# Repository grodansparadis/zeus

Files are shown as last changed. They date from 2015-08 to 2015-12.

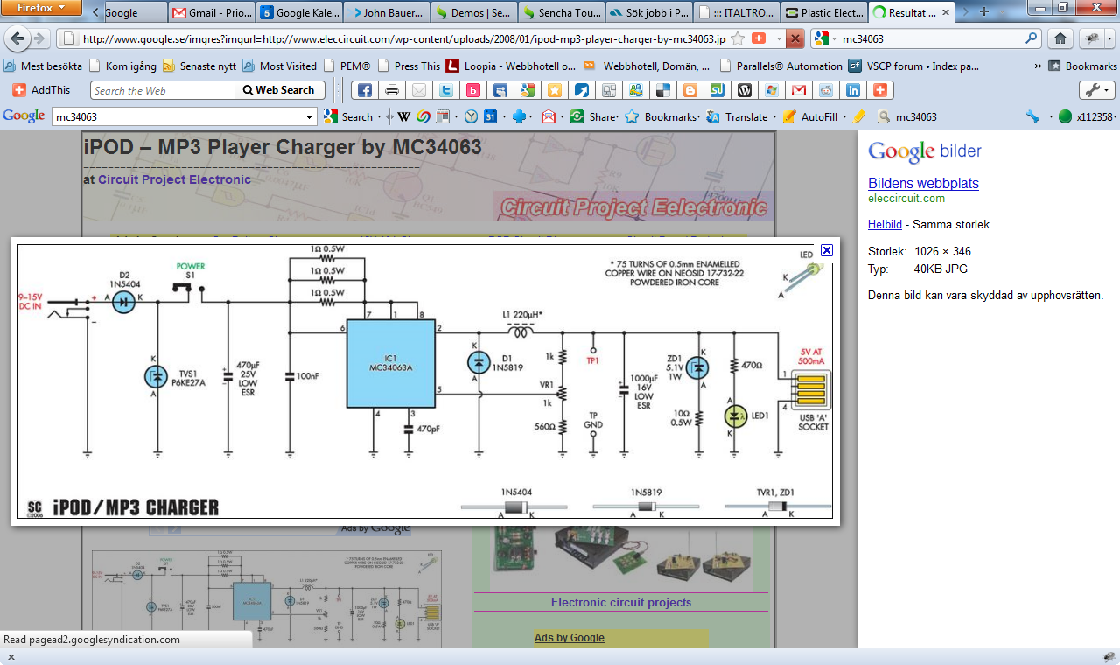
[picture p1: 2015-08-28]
docs/2011-05-05 16-10-04.png

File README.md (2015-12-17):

# zeus
Ethernet carrier board for VSCP
<hr>

This project is part of the <a href="http://www.vscp.org">VSCP (Very Simple Control Protocol) project</a>. 

<hr>

This project is licensed under the 
<a href="http://creativecommons.org/licenses/by-nc-sa/3.0/">Creative Commons open source license Attribution-NonCommercial-ShareAlike 3.0 Unported</a>. 
Other license options are available by conacting <a href="malto:info@grodansparadis.com">Paradis of the Frog AB</a>

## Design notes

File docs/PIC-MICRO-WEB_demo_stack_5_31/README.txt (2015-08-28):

0. INTRODUCTION

It is highly recommended to read the excellent stack documentation from Microchip before proceeding. The demo is based on the original Microchip Application Libraries. The TCPIP version is 5.31 - part of Microchip Application Libraries v2010-10-19.

--------------------------------------------------------------------------------

1. RUNNING THE DEMO

You might use the prebuilt files in directory "Prebuilt". If you wish to build the demo yourself please continue reading.

Open "./TCPIP Demo App/TCPIP Demo App-C18.mcw" workspace. 

*Note: In order to compile successfully you need to have MC18 installed. Please also ensure that project directories are set properly to match path of the compiler (i.e. right-click the project->Build Options...->Directories tab).
	
Now you can compile the project and download it to the board. Of course, you can also use the project as a starting project for your custom application.

2. UPDATING THE WEB PAGE

The source web page files for PIC-MICRO-WEB are located in 
	./TCPIP Demo App/WebPagesOlimex"
	
You should run the "./Microchip/TCPIP Stack/Utilities/MPFS2.exe" to regenerate the image file (default is "MPFSImg2.bin") that shoulb be uploaded to the flash memory of the board.

Then, assuming PIC-WEB has IP address 192.168.0.30, open the following URL in your web browser: "http://192.168.0.30/mpfsupload". Browse to "MPFSImg2.bin" and upload it. After that the new web page should be available.

*Note: You might also use the ready MPFSImage2.bin located in directory "Prebuilt"

3. LOCATING PIC-WEB

Run the "./Microchip/TCPIP Stack/Utilities/Microchip Ethernet Discoverer.exe" utility in order to find what IP address has PIC-WEB fetched from DHCP. Another option is to connect a serial port to the board RS232 connector, configure your terminal application for 19200 8N1, and see the board status messages during power up.

*Note: Default setting of the board is to use DHCP to retrieve network configuration (IP address, etc.).. This can be modified by editing the "TCPIPConfig.h".

Last edit: 11 Nov 2013

Special thanks to Paolo for providing this demo!

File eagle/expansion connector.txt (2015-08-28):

Pinput for expansion connector
==============================

1	GND
2	GND
3	RC7/RX1/DT1		Motherboard RX. Output on daughterboard.
4	RC6/TX1/CK1		Motherboard TX. Output on daughterboard.
5	SCK1 (SCL1)		SPI or I2C clock. (Add 4.7K pull-up for I2C on daughterboard)
6	SDI1 (SDA1)		SPI data in or I2C data. (Add 4.7K pull-up for I2C on daughterboard)
7	SDO1 			SPI data out.
8	RF2/AN7/C1OUT	Analog or digital pin.
9	RF3/AN8			Analog or digital pin.
10	RF4/AN9			Analog or digital pin.
11	RF5/AN10/CVREF	Analog or digital pin.
12	RF6/AN11		Analog or digital pin.
13	RG4/CCP5/P1D	Digital or capture compare input.
14	RESET			System reset. Pulled up on motherboard.
15	RB3/INT3		Digital or INT3
16	RB2/INT2		Digital or INT2
17	RB1/INT1		Digital or INT1
18	RB0/INT0/FLT0	Digital or INT0
19	RE2/P2B			Digital.
20	RE3/P3C			Digital.
21	RE0/P2D			Digital.
22	RE1/P2C			Digital.
23	+3.3V
24	+3.3V

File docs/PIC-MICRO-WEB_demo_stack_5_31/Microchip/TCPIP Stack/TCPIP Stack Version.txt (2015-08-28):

********
Microchip TCP/IP Stack Version Log:
********

Note: Please file bug-reports/bug-fixes at http://support.microchip.com/ or post 
      to the Microchip TCP/IP -> Ethernet Forum at http://forum.microchip.com/
      Look for stack updates at http://www.microchip.com/tcpip/

********
v5.31 		19 October 2010
********
Changes:
1.  Reorganized demo projects.  The TCPIP ENCX24J600 Demo App, TCPIP PIC32 ETH 
    Demo App, and TCPIP WiFi Demo App projects in stack versions 5.25 and prior 
    have all been merged into the TCPIP Demo App folder.  All four of these 
    projects were almost identical to each other, with the primary difference 
    being the network interface controller the projects were preconfigured to 
    support.  In this 5.31 TCP/IP Stack release, each hardware combination now 
    has its own MPLAB IDE project in the TCPIP Demo App folder.
2.  Reorganized HardwareProfile.h and TCPIPConfig.h structure for the TCPIP Demo 
    App, TCPIP Google PowerMeter Demo App, and TCPIP WebVend App projects.  Now, 
    instead of having one massive HardwareProfile.h file that supports a 
    multitude of hardware platforms simultaneously, simple individual 
    hardware profiles have been created for specific hardware combinations and 
    placed in the "Alternative Configurations" sub-folder.  The correct hardware 
    profile or TCPIP config file is selected by #including "HardwareProfile.h" 
    or "TCPIPConfig.h" as in previous stack versions.  However, the active 
    hardware profile or config file from the Alternative Configurations folder 
    is selected by a preprocessor macro defined in the MPLAB project settings 
    (passed on the command line to the compiler).
3.  Added HTTP_SAVE_CONTEXT_IN_PIC_RAM option to TCPIPConfig.h (HTTP2 server 
    module).  This option, when enabled, will increase HTTP2 server performance 
    when servicing multiple simultaneous connections at the expense of using 
    more PIC RAM.
4.  Added automatic TPIN+/- polarity swapping logic to ETH97J60.c driver for 
    PIC18F97J60 family devices.  Some 3rd party Ethernet switches, routers, and 
    end devices have their TX+/- pins wired backwards such that the remote TX+ 
    signal connects to the PIC TPIN- pin and the remote TX- signal connects to 
    the PIC TPIN+ pin.  Because 10BaseT Ethernet signaling is polarized and the 
    PIC18F97J60 family does not implement an auto-polarity feature, this 
    normally prevents all RX communications with these non-IEEE 802.3 compliant 
    link partners.  To work around this incompatibility, it is possible to 
    implement circuitry to swap the RX+ and RX- signals before reaching the 
    TPIN+ and TPIN- pins.  The PICDEM.net 2 Rev 6 reference design includes this 
    necessary circuitry (U6, U7, R54, and RX_SWAP GPIO output pin from PIC).  
    This stack version automatically controls the RX_SWAP signal based on the 
    ETH_RX_POLARITY_SWAP_TRIS and ETH_RX_POLARITY_SWAP_IO definitions in 
    HardwareProfile.h.  If these macros are undefined, then the automatic 
    polarity swapping feature is disabled in the ETH97J60.c driver.
5.  Added portable LFSRRand() and LFSRSeedRand() public functions to Helpers.c 
    and removed all references to C rand() and srand() functions.  The C rand() 
    function returns a 15 bit integer on 8 and 16 bit PICs, but a 31 bit integer 
    on PIC32s.  The LFSRRand() function returns a 16-bit integer, regardless of 
    which PIC you are using.
6.  Added support for various SST/Microchip brand SST25xxxxx SPI Flash chips to 
    SPIFlash.c driver.  Previously only devices supporting the Auto Address 
    Increment (AAI) Word Program opcode (0xAD) would work.  Now, devices such as 
    the SST2525VF010A should work, which require the AAI Byte program opcode 
    (0xAF) instead.
7.  Removed support for Spansion brand SPI Flash chips in the SPIFlash.c driver.  
    If your application is already using one of these devices, continue to use 
    the SPIFlash.c/.h files from TCP/IP Stack 5.25.  These older files are API 
    compatible with the current version, so can be dropped in by simply 
    overwriting the SPIFlash.c and SPIFlash.h files.
8.  Removed a -4 offset from the advirtised TCP Maximum Segment Size option 
    (MSS) and TCP_MAX_SEG_SIZE_RX configuration value in TCP.c.  The default 
    TCP MSS advertised is now 536 instead of 532.    
9.  For Wi-Fi projects in the TCPIP Demo App folder, changed 
    MY_DEFAULT_LIST_RETRY_COUNT to WF_RETRY_FOREVER instead of 3.  This
    changes default connection behavior to keep trying to connect instead of
    just trying 3 times which makes more sense for demonstration.
10. Changed WF_Connect() beacon timeout to 40.
11. IFConfig command in TCPIP WiFi Console Demo App modified to return 
    application-perspective MAC address from the AppConfig structure, and not 
    the Wi-Fi serialized MAC address (they may not match if user desired custom 
    MAC).
12. Updated the TCP/IP Configuration Wizard.  The user can now configure 
    wireless settings and stack settings seperately.  Because of the changes to 
    the TCPIPConfig.h file, the user must now select the specific copy of 
    TCPIPConfig.h (or any of its variants) instead of selecting a project 
    directory. Added the ability to select WF_RETRY_FOREVER in the Wi-Fi 
    configuration settings.  Added a selection parameter for BSD socket count. 
    Added validation to check for the proper number of Berkeley sockets and TCP 
    performance test sockets in the socket configuration screen (Advanced 
    Settings) if either of these features are enabled.  Added the ability to 
    create sockets of the same type with different TX/RX buffer sizes in the 
    socket configuration screen.
13. Updated the TCPIP WebVend Demo App to support Wi-Fi in several 
    configurations.
14. Modified the Google PowerMeter demo to automatically determine the 
    date/time from the HTTP module if the date/time cannot be obtained from the 
    SNTP module.
15. Added a new Google Map project example to the Combo Demos folder.  This 
    example runs on a PIC24FJ256DA210 Development Board + Fast 100Mbps Ethernet 
    PICtail Plus (or Ethernet PICtail Plus) + Truly 3.2" 240x320 display, 
    TFT_G240320LTSW_118W_E (or Powertip 4.3" 480x272 display, 
    PH480272T_005_I11Q).  It also can run on the PIC32 Multimedia Expansion 
    Board + PIC32 Ethernet Starter Kit.  This demo connects to the Internet, 
    sends an HTTP query for a specific map tile to the Google Static Maps API, 
    and then displays the compressed tile to the graphics display.  For more 
    information, see the "Getting Started - Running the Graphics Google Map 
    Demo.htm" file in the Combo Demos\Google Map folder.
16. Added preliminary SNMPv3 module.  This module, enabled with the 
    STACK_USE_SNMPV3_SERVER option in TCPIPConfig.h, implements the Simple 
    Network Management Protocol, version 3.  Among other things, SNMPv3 adds 
    secure authentication and cryptographic privacy as compared to SNMPv2C.  
    This implementation currently only supports AES encryption (no DES support).  
    It also has only been tested with the PIC32 Ethernet Starter Kit (TCPIP 
    Demo App - C32 - PIC32_ENET_SK_DM320004_INTERNAL_ETHERNET.mcp MPLAB IDE 
    project).  SNMPv3 on PIC18, PIC24, and dsPIC platforms are not supported at 
    this time.  Because AES encryption has specialized United States export 
    requirements, this TCP/IP Stack release does not include the required AES 
    library to enable SNMPv3.  To obtain the needed AES library, you must 
    purchase SW300052 v2.6 or later.  Older v2.5 and previous versions include 
    AES related files on them, but do not include the new AES files required by 
    SNMPv3.  For more information on using SNMP, refer to the TCP/IP Stack Help 
    (Demo Information -> Available Demos -> TCPIP Demo App -> Demo Modules -> 
    Network Management (SNMP) Server).
17. Altered the SaveAppConfig() function in MainDemo.c to store a more robust 
    signature to EEPROM/SPI Flash when saving the AppConfig structure.  In v5.25 
    and prior stack versions, when EEPROM or SPI Flash memory was available, the 
    stack would automatically write a one byte marker character to address 
    0x000000 in the EEPROM/Flash indicating if a valid AppConfig structure was 
    stored in the non-volatile memory.  This resulted in the EEPROM/Flash 
    contents being organized like the following:
        Address                 Data Contents
        ===================     ==============================================
        0x000000:               Marker Byte
        0x000001:               AppConfig structure
        MPFS_RESERVE_BLOCK:     Start of MPFS/MPFS2 image containing web pages
    In this stack version, EEPOM/Flash contents will now contain:
        Address                 Data Contents
        ===================     ==============================================
        0x000000:               Length of AppConfig structure (16-bit integer)
        0x000002:               IP checksum of the AppConfig default values, as 
                                defined in TCPIPConfig.h and WF_Config.h 
                                (16-bit integer).
        0x000004:               IP checksum of the subsequent EEPROM/Flash 
                                bytes of the AppConfig values.
        0x000006:               AppConfig structure
        MPFS_RESERVE_BLOCK:     Start of MPFS/MPFS2 image containing web pages
   The additional checkums allow automatic detection to occur if you change one 
   of the values in TCPIPConfig.h or WF_Config.h that affects AppConfig.  If 
   you change one of the values in code, then upon boot up, the application 
   will automatically detect this change and start using the values that you 
   selected in code.  If, at run time, you decide to change the AppConfig 
   values and commit the changes to EEPROM/Flash, then the stack will 
   subsequently use the run-time saved values on future reboots.  The checksum 
   at offset 0x000004 ensures that if any corrupted AppConfig contents are 
   found in EEPROM/Flash (ex: power is lost between writing the signature 
   structure and actual AppConfig structure, or code unintentionally overwrites 
   something in the AppConfig memory area), then the original defaults defined 
   in TCPIPConfig.h and WF_Config.h will be used instead of the corrupted 
   values.  This EEPROM/SPI Flash change affects all projects except TCPIP 
   Internet Radio App, TCPIP Internet Bootloader App, and all PIC32 Starter Kit 
   projects since these projects do not have or use external EEPROM or SPI 
   Flash memory.

Fixes:
1.  Fixed a UDP bug in which a transmitted packet would have been addressed 
    to the wrong destination node if the UDP socket received a broadcast packet 
    from a different remote node from the last received packet, but using the 
    same source port number as the last received packet.  The 
    FindMatchingSocket() function in UDP.c will now always change the local 
    socket parameters to send to the most recent remote node's unicast IP 
    address, regardless of if the last received packet was addressed to a 
    multicast or broadcast destination.  Thanks go to Billy Walton for reporting 
    this erroneous behavior.  If you wish to change the destination IP/MAC 
    addresses or port number for a UDP packet that you are ready to send, write 
    the new parameters to the UDPSocketInfo[SocketHandle] global structure 
    before calling UDPFlush().  This structure contains remoteNode and 
    remotePort parameters for the remote IP address/MAC address and remote UDP 
    port, respectively.  You can also read these values to obtain the remote 
    addressing parameters for the last received packet on the given UDP socket.  
    Note that "SocketHandle" refers to the UDP socket handle returned by the 
    UDPOpen() API, not the literal string "SocketHandle".
2.  Fixed ADC state save/restore bug in GenerateRandomDWORD() function in 
    Helpers.c.  PIC24, dsPIC, and PIC32 platforms require the ADC ON/ADON bit to 
    be cleared before modifying certain other ADC register contents.
3.  Fixed an ENC28J60 MAC/MII register write timing violation when using a 
    PIC24H or dsPIC at over 33MIPS.  There was inadequate Chip Select hold time 
    provided, violating the 210ns minimum specified in the ENC28J60 data sheet.  
    This violation may have resulted in certain devices losing the ability to 
    receive packets (due to the MARXEN bit, MACON1<0>, getting cleared 
    unintentionally).
4.  Fixed an ENCX24J600.c driver bug in which operating at 100Mbps with the 
    ENC424J600/624J600 Ethernet controller, it would be possible for the 
    MACGetHeader() function to issue a Reset() operation under rare 
    circumstances.  The PIC would reset whenever the PHY detected an illegal 
    symbol during 4B5B decoding but guessed the correct 4B symbol such that no 
    data corruption or CRC error occurred.  This condition results in a valid 
    packet being received but with the Received Ok Receive Status Vector bit 
    being clear (RSV<23> == 0).  This issue would become more probable when 
    using very long Ethernet cables (ex: 100 meters) and receiving a lot of 
    data.
5.  Fixed a TCP bug in which calling TCPDisconnect() to close a connection when 
    the remote node's RX window was 0 bytes would have caused the stack to enter 
    an infinite loop sending duplicate ACK packets.
6.  Fixed Wi-Fi bug that caused assert condition if too many management messages 
    were being received during data traffic.
7.  Fixed Wi-Fi bug that caused WF_EVENT_CONNECTION_RESTABLISHED event case to 
    send the wrong notification to the app.  
8.  Fixed Wi-Fi bug that caused assert failure with Scratch move failure.
9.  Fixed Wi-Fi bug in WF_CAGetChannelList() and WF_CAGetSecurity that caused 
    failure.
10. Fixed Wi-Fi EasyConfig bug that required development boards to be manually 
    reset even after new network was selected.
11. Fixed MRF24WB0 bug that caused assert if invalid WPA/WPA2 key was entered.
12. Fixed Wi-Fi power management bit behavior in PS-Poll frame that was causing 
    some AP’s to never send data or disconnect when in power save mode.
13. Fixed a TCP bug in which attempting to open a client TCP socket to a remote 
    server, specified by IP address (not DNS address), that was offline, but 
    who's MAC address was already cached by the ARP client, would result in 
    endless back-offs. For example, when attempting to contact the remote node 
    (that was not responding), the TCP module would have transmitted a SYN at 
    time T=0 seconds, T=1s, T=3s, T=7s, T=15s, T=31s, T=63s, T=127s, T=255s, 
    etc.  The exponential back-off between retransmissions would grow 
    indefinitely until the retransmission interval would have grown so large 
    that effectively no-retransmissions would be occurring.  Assuming the 
    application wasn't written with its own timeout to prevent endless waiting, 
    this would prevent the socket from automatically establishing the 
    connection to the remote server once the server came back online.  With this 
    TCP fix, the exponential back off now saturates after TCP_MAX_RETRIES (5) 
    back offs and continues to retransmit using the same interval.  By default, 
    this means SYN transmissions will occur at T=0 seconds, T=1s, T=3s, T=7s, 
    T=15s, T=31s, T=63s, T=95s, T=127s, etc.  After 5 back-offs the 
    retransmission interval stops growing and stays constant at 32 seconds.
14. Fixed an RSA computation bug that would cause the RSA module to never 
    complete if you attempted to compute y = x^e % n where e = 3 (or similar 
    number < 256 with only 0, 1, or 2 bits set).  Thanks go to Kevin Maidment 
    for pointing this error out and suggesting a solution.  Note, that this fix 
    to RSA.c is not distributed with the ordinary TCP/IP Stack due to United 
    States export restrictions.  To get this fix, you must repurchase SW300052.  
    This fix is included in SW300052 v2.6 or later.  If you don't have CD media 
    to identify the SW300052 version that you have, you can test the RSA.c file 
    that you have.  RSA.c in SW300052 v2.6 has a CRC32 checksum of 0x91F66711.  
    RSA.c in v2.5 and prior had a checksum of 0xB1E8B0CC.

Known Problems:
1.  Telnet server module does not implement a lot of Telnet functions.  As a 
    result, it will likely not display correctly or work at all with some Telnet 
    clients.  The server was tested with the Microsoft telnet.exe utility which 
    is provided with Microsoft Windows.
2.  If the DHCP client and DHCP server are used at the same time and you connect 
    two similar boards to each other (ex: two PICDEM.net 2 boards connected via 
    a crossover cable), a race condition can occur where both nodes will disable 
    their DHCP server and neither board will get a successful DHCP lease.  If 
    this unlikely scenario occurs, as a work around, simply reset one of the 
    boards to reenable it's DHCP server.
3.  LCDBlocking.c timing for the LCD_E_IO enable signal is too fast to meet 
    published data sheet limits for various LCD controllers when compiling for 
    a PIC32 running at > 43MHz.  Despite this potential timing violation, the 
    LCD does normally work correctly on the precompiled PIC32 demos for the 
    Explorer 16 at 80MHz.

********
v5.25 		07 May 2010
********
Changes:
1.  Added support for the Microchip MRF24WB0 802.11 WiFi controller (module 
    part number MRF24WB0MA).  This product is intended as a backwards 
    compatible, drop in replacement to the ZG2100.  The MRF24WB0MA should work 
    with previous TCP/IP Stack versions as if it were a ZG2100M, but when the 
    MRF24WB0MA is used with this (5.25) and future TCP/IP Stack versions, 
    feature improvements inside the MRF24WB0 allow the TCP/IP Stack code/RAM 
    size to be smaller and run faster.  
2.  Dropped support for the ZeroG ZG2100 802.11 WiFi controller.  Applications 
    that must stay with this device should continue to use TCP/IP Stack 
    version 5.20b or earlier.  All new projects or preexisting projects 
    undergoing updates should be developed with the MRF24WB0 instead.
3.  The WiFi connection management state machines now run on the MRF24WB0 
    instead of the PIC host, freeing up code and data space.  Connection profiles 
    can be created and the connection algorithm fine-tuned by the PIC 
    application. In the WiFi demos see the WF_Connect function in MainDemo.c for 
    an example of how to configure and then establish a WiFi connection.  The
    programming model has changed to an API model which is documented in 
    'TCPIP Stack Help.chm'.
4.  Changed "VERSION" macro definition in TCPIP.h to "TCPIP_STACK_VERSION".  
    "VERSION" is overly generic and will likely conflict with other identical 
    tokens one may use in their application code or source libraries.
5.  Added support for the PIC24FJ256GA110, PIC24FJ256GB110 and PIC24FJ256GB210
    PIMs for the Explorer 16.  Note that when using the PIC24FJ256GA110 
    general purpose PIM, the Ethernet PICtail Plus, Fast 100Mbps Ethernet 
    PICtail Plus, MRF24WB0MA Wi-Fi PICtail Plus, or other SPI PICtail daughter 
    board should be installed in the middle SPI2 slot of the Explorer 16, not 
    the ordinary topmost SPI1 slot used by other PIMs, including the 
    PIC24FJ256GB110 and PIC24FJ256GB210 ones.  The software is set up to use 
    SPI2 for the PIC24FJ256GA110 PIM to avoid incompatibilities with silicon 
    revision A3, which does not allow the SCK1 pin to be configured as a PPS 
    output.
6.  Added support for the PIC24FJ256DA210 Development Board.
7.  Added TFTPUploadRAMFileToHost(), TFTPUploadFragmentedRAMFileToHost() and 
    TFTPGetUploadStatus() APIs to the TFTPc.c file.  These APIs provide a very 
    simple means of uploading a whole file to a remote TFTP server without 
    requiring a great deal of application state machine logic.  These APIs 
    require the DNS client module to be enabled (STACK_USE_DNS must be defined, 
    in addition to STACK_USE_TFTP_CLIENT).
8.  Added a dummy DNS Server module.  This server always sends the local IP 
    address in response to all queries received.  When using the PIC DHCP 
    server, its purpose is to allow a user to type anything into a web browser 
    (ex: http://asdf/) and still receive the web page provided by the PIC, much 
    as a hotel or airport WiFi router will serve to you before you've paid or 
    agreed to the network's terms of service.  This DNS server module is 
    implemented in DNSs.c, requires one UDP socket, and is enabled via the 
    STACK_USE_DNS_SERVER option in TCPIPConfig.h.
9.  Changed SPIFlash.h file defaults to target an SST SPI Flash with 4096 byte 
    sectors instead of a Spansion Flash with 65536 byte sectors.  These new 
    defaults are, among other reasons, in support of the PIC24FJ256DA210 
    Development Board, which has an SST SST25VF016B on it.
10. Made TCP Keep-Alive packets consistently get sent TCP_KEEP_ALIVE_TIMEOUT 
    (default 10 seconds) after the last socket TX or RX activity.  In earlier 
    stack versions, if the local node transmitted some data and then let the 
    socket go idle, the first Keep-Alive packet sent would use the 
    TCP_START_TIMEOUT_VAL (default 1 second) timer value before getting sent.  
    While benign in terms of application behavior, these faster than normal 
    keep-alive transmissions were distracting when viewed in Wireshark or other 
    packet capture tools.
11. Disabled STACK_USE_DYNAMICDNS_CLIENT option in TCPIPConfig.h by default for 
    the TCPIP Demo App and TCPIP ENCX24J600 Demo App projects.  This option was 
    enabled by default in earlier stack releases.  This was done to save code 
    size and allow out-of-box compilation on devices with 128KB of Flash when 
    not using compiler optimizations.  The TCPIP PIC32 ETH Demo App project 
    continutes to have this option enabled by default.
12. Added SNMP v2 TRAP PDU format.  Macro SNMP_STACK_USE_V2_TRAP is used to 
    enable the SNMP v2 trap format.  New API function SNMPV2TrapDemo() is 
    included to support more than one variable binding to the SNMPv2 TRAP. This 
    API can be used for a single SNMPv2 TRAP variable varbind and is part of 
    CustomSNMPApp.c. A multiple variable binding demo can be enabled 
    MainDemo.c.  One should not enable both SNMPTrapDemo and SNMPV2TrapDemo 
    simultaneously.  Global flag "gSetTrapSendFlag" is used to indicate the 
    start and end of SNMPv2 trap varbinds.  If gSetTrapSendFlag is FALSE, then 
    very next variable varbind for the SNMPv2 TRAP, is the last or only one 
    variable varbind.  If gSetTrapSendFlag is TRUE, then there is another 
    variable varbind available to be part of the SNMPv2 TRAP PDU.
13. Added support for PIC32MX6XX/7XX external PHY's: SMSC 8700LAN and National 
    DP83640.
14. Added schematics and BOM for the PIC32 Ethernet Starter Kit.
15. Added the Google PowerMeter demo project. Consult the "Reference 
    Implementation for Google PowerMeter.chm" help file for more information.
16. Modified the SSL and TCP modules to create the TCPStartSSLClientEx function.
    This function will enable the SSL module to store supplementary data
    (currently only SSL Certificate Public Keys) in a structure.
17. Moved the HTTP_PORT, HTTPS_PORT, HTTP_MAX_DATA_LEN, and HTTP_MIN_CALLBACK_FREE
    macros from HTTP2.c to TCPIPConfig.h.

Fixes:
1.  The SPIFlashEraseSector() function in the SPIFlash.c file incorrectly erased 
    the sector specified by the current write pointer (set by calling 
    SPIFlashBeginWrite()) instead of the specified dwAddr parameter address.  
    This error had no impact on any TCP/IP Stack code as these parameters always 
    matched.  However, application code using the API would have been affected.  
    Thanks go to Marc Boon for reporting this issue on the Microchip Ethernet 
    forum.
2.  Fixed ENC424J600/624J600 driver for PSP modes 2, 4, 6, and 10.  The PIC's 
    PMP PMMODE<9:8> bits were not set correctly.
3.  Removed from lingering references to TickGetDiff() in FTP.c, TFTPc.c and 
    UARTConfig.c.
4.  Fixed DNS client module from returning the DNS server IP address if the DNS 
    query failed due to a server error (i.e. DNS did respond, but did not 
    return any records, such as when attempting to resolve a name that isn't in 
    the DNS).  DNSIsResolved() will now return 0.0.0.0 on any non-recoverable 
    DNS error or timeout.
5.  Fixed HTTP2 MPFS upload page being accessible from URLs that weren't an 
    exact match.  For example, in 5.20 and earlier, accessing 
    http://mchpboard/mpfsuploadASDF would still have opened the mpfsupload page.  
    Thanks go to Andrea Rivolta on the Microchip Ethernet Forum for identifying 
    this error.
6.  Improved UDP TX checksum code for the special case when the computed 
    checksum was 0x0000.  According to the UDP RFC, for this corner case, the 
    checksum should be converted to 0xFFFF before transmission to differentiate 
    from the checksum disabled case, improving error detection by a minuscule 
    amount.
7.  Fixed GetCLKOUT() function in ENCX24J600.c driver file.  Previously, 0x00 
    would always be returned, regardless of the value in the COCON bits of 
    ECON2.  The function documentation for SetCLKOUT() and GetCLKOUT() was also 
    corrected (had obsolete information ported over from ENC28J60 driver file).
8.  Fixed DHCP client rebinding bug in which the DHCP client would request the 
    wrong IP address if an unrelated DHCP OFFER or ACK message were received 
    after we transmitted a DHCP REQUEST but before we received our DHCP ACK. 
    Under rare conditions, this would have resulted in the TCP/IP stack 
    reverting to the static or AutoIP assigned address for a few seconds 
    between DHCP lease renewals.
9.  Fixed TFTP Internet Bootloader bug in which uncommon .hex files containing 
    a certain data pattern could not be uploaded correctly to the PIC18F97J60 
    family device.  For these problem .hex files, a block of 32 program words 
    (64 bytes) would remain unprogrammed (left as 0xFFFF) due to a parsing error 
    in the bootloader's DecodeHex() function.  The TFTP upload operation would 
    succeed without reporting a programming error.  The problem can be detected 
    by using an ICD3 or similar ICSP programmer and reading the program Flash 
    out of a device that is programmed with the bootloader and application .hex 
    files.  Compare the resulting memory dump to a device programmed only with 
    the application .hex file.  If you have devices deployed in the field with 
    the previous bootloader and happen to generate a  problem application .hex 
    file, you can potentially work around the bootloader bug by opening the 
    application .hex file with Notepad and appending dummy address records to 
    the beginning to move the data around in the file.  For example, at the very 
    top of the .hex file, add lines containing ":020000040000FA" until the 
    bootload process works correctly.  You may alternatively try adding spaces 
    at the end of any line, although this may make the .hex file incompatible 
    with some programming utilities.  Thanks go to Jonathan Seidmann for 
    identifying and reporting this bug.
10. Fixed SNMPv2 TRAP format issue where SNMP browser was displaying all the 
    SNMPv2 traps as SNMP version 1.  SNMP v2 TRAP pdu format is rectified.  
    Macro SNMP_STACK_USE_V2_TRAP is used to form and send a SNMPv2 TRAP PDU.  
    SNMPTrapDemo API is used for both SNMPv1 and SNMPv2 single variable 
    varbind trap.
11. Fixed an HTTP2.c server module initialization bug when using the 
    PIC32MX7XX/6XX series internal Ethernet module.  During initialization the 
    HTTPLoadConn() function would overwrite over 100 bytes of PIC RAM past the 
    end of the reserved memory allocated for the HTTP2 module.  This problem 
    would manifest itself by locking up the TCPIP PIC32 ETH Demo App-C32 demo 
    shortly after power up if you compiled TCP/IP Stack version 5.20 with the 
    MPLAB C Compiler for PIC32 MCUs (C32) version 1.11.
12. Fixed SSL client from incorrectly parsing for the server's public key in 
    rare cases where the RSA Public Key Algorithm identifier was received, but 
    the key hadn't been received by TCP yet.  Thanks go to Kevin Maimdnet for 
    identifing this error in SSL.c and reporting it via 
    http://support.microchip.com/.
13. Fixed Tick.c TickGet(), TickGetDiv256() and TickGetDiv64K() APIs sometimes 
    returning the wrong value on PIC32 platforms.  On the PIC32MX3XX/4XX family 
    devices a wrong return result would sometimes occur if using -O3 compiler 
    optimizations (maximum speed) with the Microchip MPLAB C Compiler for PIC32 
    MCUs (C32).  On the PIC32MX5XX/6XX/7XX family devices, such as the 
    PIC32MX795F512L device used on the PIC32 Ethernet Starter Kit, wrong values 
    could be returned, regardless of the compiler optimization level.

Known Problems:
1.  Telnet server module does not implement a lot of Telnet functions.  As a 
    result, it will likely not display correctly or work at all with some Telnet 
    clients.  The server was tested with the Microsoft telnet.exe utility which 
    is provided with Microsoft Windows.
2.  If the DHCP client and DHCP server are used at the same time and you connect 
    two similar boards to each other (ex: two PICDEM.net 2 boards connected via 
    a crossover cable), a race condition can occur where both nodes will disable 
    their DHCP server and neither board will get a successful DHCP lease.  If 
    this unlikely scenario occurs, as a work around, simply reset one of the 
    boards to reenable it's DHCP server.
3.  HI-TECH PICC-18 compilers are not supported in this release.  The supplied 
    HI-TECH PICC-18 MPLAB projects usually will not compile and/or link.
4.  LCDBlocking.c timing for the LCD_E_IO enable signal is too fast to meet 
    published data sheet limits for various LCD controllers when compiling for 
    a PIC32 running at > 43MHz.  Despite this potential timing violation, the 
    LCD does normally work correctly on the precompiled PIC32 demos for the 
    Explorer 16 at 80MHz.

********
v5.20 		18 November 2009
********
Changes:
1.  Added PIC32MX7XX/6XX Family integrated Ethernet controller support.  The 
    "TCPIP PIC32 ETH Demo App" folder was added to compile for the PIC32 
    Ethernet Starter Kit.  Ethernet driver files "ETHPIC32ExtPhy.c" and 
    "ETHPIC32IntMac.c" were added, in addition to the "ETHPIC32ExtPhyDP83848.c" 
    file, which is a specific driver file for the National DP83848 10/100 PHY.
2.  Added RFC 3927 Auto IP module.  This module will automatically assign a 
    local IP address to the node in the 169.254.xxx.xxx private address range 
    (subnet mask 255.255.0.0) if a DHCP server is not present on the network or 
    the DHCP client is disable.  The exact IP address chosen will be 
    pseudo-random, but as required by the protocol, it will perform gratuatous 
    ARPs to avoid clobbering anyone else's IP address.  Also, unless there is an 
    address collision with a preexisting node on the network, the IP address 
    generated by the Auto IP module will not change between power cycle events 
    (random number generator is seeded by local MAC address).  To enable this 
    module, STACK_USE_AUTO_IP must  be defined in TCPIPConfig.h.  When compiled 
    in, the module defaults to enabled, but will automatically yield to the 
    DHCP client module, which has higher priority.
3.  Added "TCPIP MDD Demo App" beta application projects.  Projects in this 
    folder store the HTTP2 web pages in external FAT16/FAT32 formatted SD card 
    or USB Mass Storage media instead of an MPFS2 formatted EEPROM or SPI Flash.  
    For more information on these projects, see the "Running the TCPIP MDD Demo 
    App (Beta Release).pdf" file in the Microchip\Help folder.
4.  Expanded XEEReadArray() API's third length parameter from a BYTE to a WORD.
5.  Converted all variable declarations and type casts of TICK data type to 
    DWORD.  The TICK typedef is now deprecated and will be removed in a future 
    stack release.  This data type conflicts with the TICK structure used in 
    certain other Microchip software libraries.  
6.  Added TCP_WINDOW_UPDATE_TIMEOUT_VAL option to the TCP.c file (default 
    200ms).  This timeout controls the time after calling TCPGet() or 
    TCPGetArray() before the stack will transmit a RX window update to the 
    remote node.  Historically, the TCP_AUTO_TRANSMIT_TIMEOUT_VAL value was 
    used for this purpose (default 40ms).  This change decreases the net window 
    update transmission overhead.  If this adversely affects your application 
    RX performance (unlikely, but possible for certain communications patterns), 
    set TCP_WINDOW_UPDATE_TIMEOUT_VAL equal to or shorter than 
    TCP_AUTO_TRANSMIT_TIMEOUT_VAL to get the same or better behavior relative 
    to previous stack versions.
7.  Split TCP_MAX_SEG_SIZE configuration constant in TCP.c into separate 
    TCP_MAX_SEG_SIZE_TX and TCP_MAX_SEG_SIZE_RX configuration constants.  
    Previously, TCP_MAX_SEG_SIZE was used to limit both the maximum size of 
    transmit and receive packets.  In cases where large TX FIFOs are allocated, 
    and the remote node advirtises a large Maximum Segment Size TCP option, this 
    change improves TCP transmit performance by roughly 10%.
8.  Renamed "Internet Radio App", "Internet Bootloader App" and "WiFi Iperf 
    App" folders to "TCPIP Internet Radio App", "TCPIP Internet Bootloader App"
    and "TCPIP WiFi Iperf App" respectively.  These new names ensure consistent 
    folder placement when viewing the Microchip Solutions folder with other 
    Microchip Application Libraries installed.

Fixes:
1.  Fixed SSL functionality (ex: HTTPS server) from failing when using the 
    ENC424J600 and ENC624J600 Ethernet controllers.  In stack versions 5.00 and 
    5.10, the BFSReg() and BFCReg() functions were being incorrectly used to set 
    and clear CRYPTEN (EIR<15>).  ENC424J600/624J600 silicon errata #6 on 
    production silicon revision A2 prevents BFSReg() and BFCReg() from being 
    able to modify CRYPTEN.  This resulted in the SSL RSA encrypt/decrypt 
    operations from ever finishing.  The ENC424J600/624J600 errata #6 workaround 
    is now implemented in the ToggleCRYPTEN() function in ENCX24J600.c.
2.  Fixed an RSA padding error in the ENCX24J600.c's version of RSASetData() and
    RSASetE() functions.  This fixes the Bad Record MAC problem when using SSL 
    client APIs with the ENC424J600 and ENC624J600, as mentioned in the 5.10 
    stack release notes' Known Problems section.  Although unknown at the time 
    of release this problem also occurred in stack version 5.00.
3.  Fixed DNS client from mishandling DNS responses that did not use name 
    compression.  Thanks go to Will Stone on the Microchip Ethernet forum for 
    identifying this bug.
4.  Fixed an ExtractURLFields() API bug which would incorrectly parse the URLs 
    containing other URLs.  Ex: 
    "http://www.google.com/search?q=http://www.microchip.com/"
5.  Fixed TickGet(), TickGetDiv256(), and TickGetDiv64K() APIs from potentially 
    returning an incorrect time value (0x10000 ticks less than it should have) 
    on rare occasions when using a PIC32 and with compiler optimizations turned 
    on.  The Tick.c module was also revised so that the IEC0 register does not 
    get written to via a load-modify-store operation on PIC32s so that it is 
    now possible for other application ISR functions to write to IEC0 without 
    risking state corruption.
6.  Fixed PIC32 Starter Kit Debugger losing access to the PIC32 target when the 
    project was run.  JTAG was being disabled at run time, but the PIC32 
    Starter Kit Debugger requires JTAG to communicate with the debug 
    executive.  JTAG is now conditionally disabled on PIC32s when the 
    __MPLAB_DEBUGGER_PIC32MXSK macro is undefined.
7.  Fixed a Berkeley sockets API bug in which calling closesocket() on a 
    SOCK_STREAM type socket (TCP) did not actually close the socket if the 
    remote node did not first send a FIN to the local node. This would leak a 
    TCP socket each time the affected API calling sequence occurred and result 
    in no FIN getting transmitted to the remote node.
8.  Fixed an HTTP2 filename parsing bug that would occur when a web browser 
    submitted a request for a file with hex encoded characters in it.  For 
    example, with stack version 5.10 and Firefox 3.5.3, typing 
    "http://mchpboard/%70rotect" into the URL field would have resulted in an 
    HTTP 404 not found error when "http://mchpboard/protect/index.htm" should 
    have been returned instead.  Thanks go to Steve Tuttle for reporting this 
    issue and suggesting a solution.
9.  Fixed a Berkeley sockets API bug in which calling recvfrom() on a datagram 
    type socket (UDP) would return an incorrect remote IP address and port 
    number when the from pointer was non-NULL.
10. Fixed HTTP2 server bug in which the HTTPReadPostName() function was failing 
    to convert the field name from URL encoding to plain-text.  If the browser 
    posted, for example, a field named "Stock Remaining", it would have been 
    incorrectly returned from HTTPReadPostName() as "Stock+Remaining".
11. In Stack 5.10, any new values you saved into AppConfig via the Network 
    Configuration demo web page would have been mishandled for WiFi projects.  
    HTTPPostConfig() in CustomHTTPApp.c of the TCPIP WiFi Demo App and TCPIP 
    Iperf Demo App projects were corrected so that they now write a magic 0x61 
    marker into EEPROM/SPI Flash address 0x0000 to inidicate that the AppConfig 
    structure is valid in EEPROM/SPI Flash.  This prevents the InitAppConfig() 
    function in MainDemo.c from restoring the default settings when changing 
    the values through the Network Configuration page.
12. For WiFi projects, a Gratuitous ARP Work-around was implemented to work 
    around cases where access points send broadcast messages at data rates that 
    the ZG2100 cannot listen to. The define USE_GRATUITOUS_ARP (in 
    TCPIPConfig.h) turns this feature on or off.

Known Problems:
1.  Telnet server module does not implement a lot of Telnet functions.  As a 
    result, it will likely not display correctly or work at all with some Telnet 
    clients.  The server was tested with the Microsoft telnet.exe utility which 
    is provided with Microsoft Windows.
2.  If the DHCP client and DHCP server are used at the same time and you connect 
    two similar boards to each other (ex: two PICDEM.net 2 boards connected via 
    a crossover cable), a race condition can occur where both nodes will disable 
    their DHCP server and neither board will get a successful DHCP lease.  If 
    this unlikely scenario occurs, as a work around, simply reset one of the 
    boards to reenable it's DHCP server.
3.  HI-TECH PICC-18 compilers are not supported in this release.  The supplied 
    HI-TECH PICC-18 MPLAB projects usually will not compile and/or link.
4.  ENC624J600 PSP modes 2, 4, 6, and 10 do not work at this time.  Some 
    Parallel Bit Bang modes may not work either.  Some minor firmware changes 
    are needed.
5.  TCPIP ENCX24J600 Demo App-C18.mcp project does not compile by default using 
    MPLAB C Compiler for PIC18 MCUs (C18) version 3.34.  There is not quite 
    enough program memory available on the PIC18F97J60 for the large number of 
    selected stack features to allow linking.  To get this project to compile, 
    turn on compiler optimizations or disable one of the modules in 
    TCPIPConfig.h (ex: comment out STACK_USE_DYNAMICDNS_CLIENT).

********
v5.10 		29 July 2009
********
Changes:
1.  Added SSL capability to the Telnet server.  If STACK_USE_SSL_SERVER is 
    defined, the Telnet server will now listen on port 992 for SSL secured 
    connections.  If you do not have a telnets client, you can use an SSL proxy, 
    such as stunnel (http://www.stunnel.org/) to add SSL/TLS support to any 
    telnet client.
2.  Moved a number of string pointer tables in the HTTP.c, HTTP2.c, FTP.c, and 
    DynDNS.c files to allocate in ROM instead of RAM.  This reduces around 120 
    bytes of RAM usage in the HTTP2 server when compiled for the PIC18 or 
    PIC24/dsPIC platforms.  The gains are even greater on PIC32 platforms.
3.  Added redefinition of SPIRAM*(), SPIFlash*(), and XEEPROM*() functions so 
    that when compiled and used without proper HardwareProfile.h definitions, 
    a more descript linker error will be generated instead of a mysterious 
    symbol not found error.
4.  Added several new APIs:
    - ExtractURLFields() in Helpers.c.  This function provides an easy
      means of parsing an URL string and extracting the protocol, hostname, 
      port, file path, etc.  Currently, this function is commented out to save 
      code space as no stack modules require it.  However, it should work 
      correctly if you simply uncomment it (remove the #if 0...#endif around 
      it).
    - strnchr() in Helpers.c.  Finds the first occurrence of a character within 
      a string but limited to a maximum length before giving up.
    - TCPPeek() and TCPPeekArray() in TCP.c.  Reads from a TCP socket's RX 
      FIFO buffer without removing the data from the stream.
    - TCPClose() in TCP.c.  Disconnects a socket from the remote node (if 
      connected) and closes the socket handle, including for server type 
      sockets.  This function is identical to the TCPDisconnect() API except 
      for the handling of server sockets.  TCPDisconnect() returns server 
      sockets to the listning state and maintains the socket handle.  TCPClose() 
      closes the socket and frees all associated resources, invalidating the 
      socket handle.
5.  Updated the DHCP client module:
    - Modified so that it wouldn't attempt to transmit DHCP Discover packets 
      when the MAC layer reports no link (MACIsLinked() == FALSE).  This avoids 
      main() while(1) loop performance degredation when you unplug the Ethernet 
      cable or lose association to your access point.
    - Added capability of performing DHCP discovers and requests without 
      setting the BOOTP broadcast flag.  Now, the DHCP client module will start 
      up and attempt to obtain an IP address with the broadcast flag set, but 
      if it fails the next DHCP retry will attempt to obtain the IP address 
      with the broadcast flag cleared.  The flag will toggle back and fourth 
      between unicast mode and broadcast mode if no DHCP server responds.  This 
      feature improves compatibility with certain DHCP servers and WiFi access 
      points.
    - Added several new APIs including DHCPInit(), DHCPIsEnabled(), 
      DHCPStateChanged(), DHCPIsBound(), and DHCPIsServerDetected().
    - Removed the DHCPFlags DHCP_CLIENT_FLAGS global variable.  Use the above
      named APIs now to get equivalent functionality.
    - Removed the DHCPBindCount global variable.  To detect if the DHCP state 
      has changed, poll the new DHCPStateChanged() function.
    - Removed the DHCPReset() API.  To perform this operation, now call the 
      DHCPInit() API.  Use 0x00 for the vInterface parameter.
6.  Removed deprecated TickGetDiff() macro.  To get a tick difference, just 
    subtract the two values in-line.  This macro was removed because it promoted
    confusing code.  Ex: a-b is different from b-a.  However, it was not 
    contextually obvious which of the two was returned when TickGetDiff(a, b) 
    was called.
7.  Added PIC32MX460F512L USB and dsPIC33FJ256GP710 PIM support to the Explorer 
    16 hardware profile for the TCPIP WiFi Demo App and WiFi IPerf App projects.
8.  Added all files needed for SSL (assuming the crypto libraries are present) 
    to the TCPIP WiFi Demo App-C30 and TCPIP WiFi Demo App-C32 projects.
9.  Converted TCPIP Demo App, TCPIP WebVend App, Internet Radio App, and 
    Internet Bootloader App MPLAB Build Directory Policy to compile in the 
    project folder instead of the source folder.  This reduces the depedancies 
    on the MPLAB project include path and allows new projects to be created by 
    copying one of the pre-existing folders (ex: copy "TCPIP Demo App" to 
    "My App") without having problems including the wrong HardwareProfile.h and 
    TCPIPConfig.h files.
10. Changed EEPROM/SPI Flash AppConfig record valid flag from 0x60 to 0x61 in 
    the TCPIP WiFi Demo App and WiFi Iperf App projects.  This will force the 
    various EEPROM settings to get erased when switching between Ethernet and 
    WiFi projects.  This is done since the AppConfig structure changes when 
    using WiFi (SSID string is added).
11. The Wifi Iperf App and TCPIP WiFi Demo App projects have been optimized for 
    better performance.

Fixes:
1.  Fixed a TCPDisconnect() API bug in which the last few bytes of data (up to 
    the TCP socket's TX FIFO size less 532 bytes) was not transmitted and no 
    FIN was sent out if the TX FIFO was full of data when TCPDisconnect() 
    was called.  This problem could have only occurred for TCP sockets with a 
    large TX FIFO (>=532 bytes).  This problem could have been observed in 
    stack version 5.00's "TCPIP Demo App-C32 EXPLORER_16 32MX360F512L ENC624J600 
    PSP 9.hex" precompiled application, among others, if you connected to the 
    TCPPerformanceTest.c module and then attempted to simultaneously access the 
    web server.  The web server was returning data very slowly and failing to 
    send the last parts of each file requested by the browser.
2.  Eliminted a potential buffer overflow vulnerability from the 
    HTTPHeaderParseContentLength() function in HTTP2.c.  If an oversized or 
    malformed Content-Length header is sent from the web client, the function 
    will now gracefully fail by returning an HTTP 400 Bad Request error page.  
    Thanks go to Mark Philipp for identifying this error and suggesting a 
    solution.
3.  Fixed a TCPOpen() problem in which the stack would continuously flood the 
    network with nearly back-to-back ARP query packets if a client socket was 
    created that specified a non-reachable remote IP address (ex: local gateway 
    was offline, or for destinations on the same subnet, the actual remote node 
    was offline).  This problem would occur only after a few minutes (<10) had 
    passed since the PIC was last reset.  Thanks go to Sergey of DPS TELECOM for
    reporting this problem.
4.  Fixed linking problem with BigInt_helpers.S (PIC24/dsPIC only) when 
    targeting a PIC with more than 8KB of RAM.  The interface registers (_iA, 
    _xA, _iB, _xB, _iR, and _wC) are now forced into near RAM.
5.  Cleaned up some uninitialized variable warnings in SNMP.c.
6.  Fixed a sequence variable traversal bug in SNMP.c.
7.  Cleaned up a large number of unsigned integer to signed integer comparison 
    warnings produced by the MPLAB C Compiler for PIC18 MCUs (C18) version 
    3.32.  With earlier versions of this compiler, these warnings would only be 
    generated as messages, so they did not get displayed by default.
8.  Some ENCX24J600 parallel bit bang modes work now.  PSP Mode 5 indirect has 
    been tested.
9.  SSL client and server capabilities now work when using the ZeroG ZG2100M 
    WiFi interface.  In the 5.00 stack release, attempting to enable the 
    STACK_USE_SSL_CLIENT or STACK_USE_SSL_SERVER TCPIPConfig.h options with 
    this network controller would have resulted in an error trap.  If an LCD 
    was present, the LCD would display “encRdPtrRAWId = encWrPtrRAWId” when the 
    error occurred.
10. The WiFi Iperf App demo locked up when an invalid command was entered at 
    the serial port console.  This is now fixed. 
11. The WiFi Iperf App demo locked up when running with a PIC32 if iwconfig was 
    typed at the serial port console.  This is now fixed.
12. The Wifi Iperf App demo, when running on the PIC24 and PIC32, and compiled 
    with the –Os option (min code size optimization), did not work.  This is 
    now fixed.
13. Change a lot of BerkeleyAPI.c internals.  This may fix a number of BSD 
    API problems.
14. Fix a problem with SNMP variables being inaccessible with certain unique 
    PEN numbers.

Known Problems:
1.  Telnet server module does not implement a lot of Telnet functions.  As a 
    result, it will likely not display correctly or work at all with some Telnet 
    clients.  The server was tested with the Microsoft telnet.exe utility which 
    is provided with Microsoft Windows.
2.  If the DHCP client and DHCP server are used at the same time and you connect 
    two similar boards to each other (ex: two PICDEM.net 2 boards connected via 
    a crossover cable), a race condition can occur where both nodes will disable 
    their DHCP server and neither board will get a successful DHCP lease.  If 
    this unlikely scenario occurs, as a work around, simply reset one of the 
    boards to reenable it's DHCP server.
3.  HI-TECH PICC-18 compilers are not supported in this release.  The supplied 
    HI-TECH PICC-18 MPLAB projects usually will not compile and/or link.
4.  ENC624J600 PSP modes 2, 4, 6, and 10 do not work at this time.  Some 
    Parallel Bit Bang modes may not work either.  Some minor firmware changes 
    are needed.
5.  SSL client code doesn't work with ENC424J600/624J600 devices.  The remote 
    server terminates the connection reporting a bad record MAC (Message 
    Authentication Code).  The SSL client does work with other controllers.

********
v5.00 		27 April 2009
********
Changes:
1.  Added ZeroG ZG2100 802.11 WiFi controller support.  The new TCPIP WiFi Demo
    App and WiFi Iperf App projects have been added, which default to using this 
    controller.
2.  Added Microchip ENC424J600/624J600 10/100 Ethernet controller support.  
    Support for this controller is provided by the new ENCX24J600.c/.h files 
    which perform the same role as the ENC28J60.c/.h or ETH97J60.c/.h files.  
    Precompiled .hex files for the ENC624J600 controller require the use of the 
    new Fast 100Mbps Ethernet PICtail Plus daughter card (AC164132).  This 
    product is not available at the time of the 5.00 TCP/IP stack release.  
    However, it is anticipated to be available for purchase on 
    www.microchipdirect.com in CQ3 2009.
3.  Significantly updated the Internet Radio App project.  Previously, radio 
    stations were hard coded into program memory at compile time.  Now, a 
    dynamic Shoutcast directory client has been implemented which allows 
    retrieval of radio stations at run time, offering endless stations you can 
    tune into.  The web pages for the radio have also been updated to allow 
    control and status reporting of the board from a web browser.
4.  Update SNMP Server (Agent) module to support SNMPv2C.  The default Demo App 
    web pages now include an SNMP reconfiguration capability to set the read 
    and write community strings. 
5.  Added ICMPSendPingToHost() and ICMPSendPingToHostROM() APIs to ICMP (ping) 
    client module.  These two APIs are available only when STACK_USE_ICMP_CLIENT 
    and STACK_USE_DNS is defined in TCPIPConfig.h.  These functions allow 
    pinging of DNS hostnames directly without the need for the application to 
    convert the hostname to an IP address first by manually calling the DNS 
    client APIs.  With this addition, the PingDemo.c file was updated to ping 
    the hostname "ww1.microchip.com" instead of a static IP address.  Previously, 
    the PingDemo would stop working a couple of months after the stack was 
    released, due to the IP address of the www.microchip.com server dynamically 
    changing.  If the DNS module is not enabled, the ping demo will instead ping 
    the local gateway IP address instead of ww1.microchip.com.
6.  Updated TCPPerformanceTest.c code.  The previous version would generate 
    incorrect speed calculations at high data rates (ex: >1Mbyte/sec).
7.  Added multiple connection support to Telnet server example module.  To 
    allow multiple connections, define MAX_SIMULTANEOUS_CONNECTIONS in Telnet.c 
    greater than 1 and create an equal number of TCP_PURPOSE_TELNET type TCP 
    sockets in the TCPSocketInitializer[] definition in TCPIPConfig.h.
8.  Added more randomness to the local port selection when opening a client-mode 
    TCP socket.  This reduces the risk of reusing a previously used port number 
    if the user power cycles the device.
9.  Updated XEE* SPI EEPROM API functions.  Writes are no longer required to 
    start on an EEPROM page boundary, and writes can now be arbitrarily long 
    without having to call XEEEndWrite() at each page boundary.  Additionally, 
    the XEEWriteArray() API has been added, which performs a similar operation 
    to the SPIFlashWriteArray() API (but with no special erase cases to worry 
    about).
10. Decoupled AppConfig storage in external SPI EEPROM or SPI Flash option from 
    MPFS_USE_EEPROM and MPFS_USE_SPI_FLASH options.  MainDemo.c will now save 
    the AppConfig structure in external non-volatile memory, even if MPFS is 
    unused (no HTTP or SNMP server modules enabled) or MPFS is using internal 
    Flash program memory to store web pages/bib information.  This change also 
    allows the XEE*() and SPIFlash*() non-volatile read/write functions to be 
    available at all times (even if MPFS is unused), as long as the appropriate 
    hardware pinout definitions are present in HardwareProfile.h.  SPI Flash and 
    SPI EEPROM are no longer mutually exclusive with each other.  However, if 
    both are enabled simultaneously, AppConfig will be stored in the EEPROM, not 
    the SPI Flash.
11. Added required SSL files to TCPIP Demo App MPLAB projects.  SSL capabilities 
    can now be turned on directly via the STACK_USE_SSL_SERVER and 
    STACK_USE_SSL_CLIENT options in TCPIPConfig.h for these projects, assuming 
    appropriate crypto libraries are installed (SW300052 available from 
    https://www.microchipdirect.com/).  With this change, the historical "SSL 
    Demo App" folder has been removed.
13. Updated HardwareProfile.h files.  This includes the addition of PIC18 
    Explorer board support, removal of the PICDEM Z profile, changes to the 
    HI-TECH PICC-18 profiles for newer compilers, among other changes.
14. Added a TCP and UDP performance test measurements table to TCPIP Stack 
    Help (TCPIP Stack Help.chm).  Access this from the "Microchip TCP/IP Stack" 
    book, "Stack Performance" page.
15. Updated MPFSlib project (Microchip.MPFS.dll file) so that C18 and C32 output 
    from the MPFS2.exe utility is now identical for MPFS2 images.  The generated 
    .c file is now compatible with both C18 and C32 compilers simultaneously.  
    Previously, the images generated for C18 would compile successfully for C32 
    projects, but would potentially operate incorrectly when compiler 
    optimizations were turned on.  Images generated for C32 would compile 
    successfully and work on C18 projects, but the C18 compiler would take a very 
    long time to process the file each time you rebuilt your MPLAB project.  Now, 
    the image generated for C18 matches the image generated for C32 and it will 
    compile fast and work correctly on both platforms, even with compiler 
    optimizations turned on.
16. Added schematics and BOMs for the Ethernet PICtail, Ethernet PICtail Plus, 
    Fast 100Mbps Ethernet PICtail Plus, Internet Radio, PICDEM.net 2, and ZeroG 
    ZG2100M PICtail development boards to the "Microchip\TCPIP Stack\Demo Board 
    Files" folder.

Fixes:
1.  Fixed a denial of service vulnerability in the NBNSGetName() function of the 
    NBNS.c file.  Previously, if a deliberately malformed packet was received, 
    the PIC RAM could have become corrupted.  Thanks go to David Talmage for 
    finding this vulnerability.
2.  Fixed Timer1 interrupt flag clearing code on PIC32 products.  Previously, 
    the Tick.c module was clearing the interrupt flag in an unsafe manner which 
    could have corrupted other interrupt flags in the IFS0 register.  Thanks go 
    to Leon van Snippenberg working on the AVIX-RT RTOS for pointing this error 
    out on the Microchip forums.
3.  Fixed SNMP up-time variable.  Previously the CustomSNMPApp.c module would 
    respond with the number of Tick API ticks that elapsed, not the number of 
    10ms time slices that elapsed.  The SNMP standard uses 10ms as its time base.
4.  Fixed BigInt_helper.asm's _masBI() and _masBIROM() functions when the Br 
    parameter's length modulo 4 was equal to 1 or 2.  This bug previously caused 
    the BigIntMod() function to sometimes go into an endless calculation loop on 
    PIC18 products when using the SSL libraries and certain combinations of 
    modulus data and length were used.  Thanks go to Vasil Stoianov on the 
    Microchip Ethernet forum for running into this defect and reporting it.
5.  Fixed SSLSessionNew() so that it wouldn't "lose" SSL sessions after waiting a 
    few hours.  This would previously make it impossible to make new SSL 
    connections after a while, but then after a few more hours, the sessions 
    would become free again.  Thanks go to Jim Stephens for identifying this 
    issue and finding the solution.
6.  Fixed an SSL 2.0 antique client hello record length calculation bug occurring 
    when a received record was > 255 bytes.
7.  Added retransmission capability to SendNotification() function in 
    CustomSNMPApp.c.  Previously, if an SNMP trap were sent, but the initial ARP 
    query or response was lost on the network, the SendNotification() code would 
    have deadlocked, and suppressed all future transmission of SNMP traps.
8.  Fixed DNS client timeout if the DNS server is unable to be ARPed.  
    Previously, the DNS client would retry ARPing the DNS server indefinitely if 
    it was offline.  Now, the DNS client will correctly abort if too many 
    attempts to ARP the DNS server fail.  Thanks go to Phil "andersop" on the 
    Microchip Ethernet forum for identifying this error.
9.  Suppressed transmission of a TCP RST packet to an unknown IP or MAC address 
    if the TCPDisconnect() function was called on a client mode socket that was 
    not finished with ARP or DNS resolution yet.  Thanks go to Phil "andersop" on 
    the Microchip Ethernet forum for pointing this behavior out.
10. Fixed TCP socket from disconnecting if the remote receive window was zero and
    TCPFlush() was still called.  Thanks go to Bob Topper for identifying this 
    issue and suggesting a solution.
11. Fixed Tick.c module returning incorrect values when TickGet() or other API 
    was used with compiler optimizations turned on.  Wrong values were observed 
    when using MPLAB C Compiler for PIC24 MCUs and dsPIC DSCs version 3.12.
12. Fixed a number of SPI communications problems that could occur when compiler 
    optimizations were turned on.  The ENC28J60 was observed to not work 
    correctly on the dsPIC33FJ256GP710 processor when compiled with MPLAB C 
    Compiler for PIC24 MCUs and dsPIC DSCs version 3.12.
13. Fixed possible MPFS2 error when using an ASM30 .s image where MPFS_Start 
    would be read using the wrong PSVPAG setting.  You must rebuild your MPFS2 
    image file (ex: MPFSImg2.s) with this stack version's MPFS2.exe utility to 
    get this correction applied.

Known Problems:
1.  Telnet server module does not implement a lot of Telnet functions.  As a 
    result, it will likely not display correctly or work at all with some Telnet 
    clients.  The server was tested with the Microsoft telnet.exe utility which 
    is provided with Microsoft Windows.
2.  If the DHCP client and DHCP server are used at the same time and you connect 
    two similar boards to each other (ex: two PICDEM.net 2 boards connected via 
    a crossover cable), a race condition can occur where both nodes will disable 
    their DHCP server and neither board will get a successful DHCP lease.  If 
    this unlikely scenario occurs, as a work around, simply reset one of the 
    boards to reenable it's DHCP server.
3.  HI-TECH PICC-18 compilers are not supported in this release.  The supplied 
    HI-TECH PICC-18 MPLAB projects usually will not compile and/or link.
4.  ENC624J600 PSP modes 2, 4, 6, and 10 do not work at this time.  Parallel Bit 
    Bang mode does not work either.  Some minor firmware changes are needed.

********
v4.55 		10 November 2008
********
SSL Note: 
   RSA.c and ARCFOUR.c have not changed between the 4.50 and 4.55 releases.  
   Although the precompiled SSL Demo App .hex files will differ, you can 
   continue to use the previous TCP/IP Stack v4.50 Encryption Add-on with this 
   4.55 stack version.

Changes:
1. Added DNS client support for a secondary DNS server address.  Previously, the 
   AppConfig.SecondaryDNSServer setting was unused.  Now, the DNS client module 
   will automatically swap the AppConfig.PrimaryDNSServer and 
   AppConfig.SecondaryDNSServer values after any DNS query timeout (or ARP 
   timeout for the DNS server) and attempt the query with the alternative 
   server.  If AppConfig.SecondaryDNSServer is disabled by setting it to the IP 
   address 0.0.0.0, the DNS client will only use the AppConfig.PrimaryDNSServer 
   value and never swap the values.  With this change, the DHCP client was also 
   updated.  If the DHCP server does not specify a secondary DNS server, then 
   the DHCP client will now set the AppConfig.SecondaryDNSServer value to 
   0.0.0.0.  Previously, it would change the AppConfig.SecondaryDNSServer 
   setting only if the remote DHCP server offered a secondary DNS server.

Fixes:
1. Updated Internet Bootloader App project to correctly detect if the 
   configuration bits are being changed or not.  Previously, the bootloader 
   always thought the configuration bits were being changed and thus had to 
   always erase the last Flash page (largest memory address) twice for each 
   firmware update.  This did not cause any functional problems or 
   specification violations, but it would decrease the effective Flash 
   endurance of the last page.
2. Fixed a TCP socket memory corruption bug that would occur if 
   TCPGetRemoteInfo() API was called twice with different socket handles 
   without an intermediate call to any other TCP API that takes a 
   TCP_SOCKET input.  Thanks go to Bob Topper for identifying this problem and 
   suggesting a solution.
3. Fixed the UDPIsGetReady() function so that it returns the number of bytes 
   remaining in the packet based on the current read location.  This is the 
   same behavior as stack versions 4.18 and earlier.  In stack versions 4.50 
   and 4.51, the UDPIsGetReady() function would always return the total number 
   of bytes in the current packet, regardless of how many bytes the read 
   pointer had been advanced through the UDPGet() and UDPGetArray() functions.  
   Thanks go to Bob Topper for identifying this problem and suggesting a 
   solution.
4. Fixed demo admin web page in TCPIP Demo App project so that the last byte of 
   the MAC address can be changed, independent of the format it was entered by 
   the user.
5. Fixed a buffer overflow bug that would occur when using the SSL server during 
   hashing of the server certificate for the initial handshake.  This error 
   previously caused several bytes of random variables elsewhere in the project 
   to get overwritten for each SSL connection.
6. BSD sockets API was updated to fix some issues.
7. LCDBlocking.c was updated to relax start up timing.  This timing fix is 
   specifically needed to support Explorer 16 boards with a Truly TSB1G7000 
   display (Novatek NT7603H controller).
8. Removed four uses of Arial Black font in MPFS2.exe utility.  On some rare PC 
   configurations, the use of this font caused the executable to not run.

Known Problems:
1. Telnet server module does not implement a lot of Telnet functions.  As a 
   result, it will likely not display correctly or work at all with some Telnet 
   clients.  The server was tested with the Microsoft telnet.exe utility which 
   is provided with Microsoft Windows.
2. If the DHCP client and DHCP server are used at the same time and you connect 
   two similar boards to each other (ex: two PICDEM.net 2 boards connected via 
   a crossover cable), a race condition can occur where both nodes will disable 
   their DHCP server and neither board will get a successful DHCP lease.  If 
   this unlikely scenario occurs, as a work around, simply reset one of the 
   boards to reenable it's DHCP server.
3. HI-TECH PICC-18 projects may not compile when targeting the external 
   ENC28J60 chip on the PICDEM.net 2 development board (instead of the 
   internal Ethernet controller).  This problem only applies when a 
   PIC18F97J60 family part is the target.  I.e. it compiles correctly for the 
   HPC_EXPLORER + Ethernet PICtail.
4. MAC.h RXSIZE precompiler test for proper range doesn't work.  This is not a 
   functional problem, just a compile-time configuration test.  Ensure that you don't 
   over allocate TCP_ETH_RAM_SIZE or MAX_HTTP_CONNECTIONS.
5. HI-TECH PICC-18 STD 9.51PL1 cannot compile DynDNS.c.  It raises an 
   "inconsistent type" error while trying to perform a ROM pointer to integer 
   cast.  The older 9.50PL3 compiler release is required to compile this file.
6. HI-TECH PICC-18 STD 9.50PL3 does not initialize several static variables 
   correctly on reset.  This behavior breaks many stack modules in the 
   TCPIP Demo App and TCPIP WebVend App projects.  Additionally, string 
   printing functions do not work correctly, so the supplied 
   "TCPIP Demo App-HITECHPICC18 PICDEMNET2 18F97J60.hex" and "TCPIP WebVend 
   App-HITECHPICC18 PICDEMNET2 18F97J60.hex" files may not correctly print the 
   board's DHCP assigned IP address on the board's LCD (if present) and UART.  To 
   avoid these severe problems, use the Microchip MPLAB C Compiler for PIC18 MCUs.  
   A free student edition can be downloaded from http://www.microchip.com/c18.

********
v4.51 		24 July 2008
********
IMPORTANT NOTE: You must use MPLAB 8.10 or higher to successfully open the 
   MPLAB projects.

SSL Note: 
   RSA.c and ARCFOUR.c have not changed between the 4.50 and 4.51 releases.  
   Although the precompiled SSL Demo App .hex files will differ, you can 
   continue to use the previous TCP/IP Stack v4.50 Encryption Add-on with this 
   4.51 stack version.

Changes:
   None.  This release includes bug fixes only.  It is very important that 
   applications using the ENC28J60 get fix item 7, below.

Fixes:
1. TCPOpen() was previously failing if you used it to start a connection with a 
   remote hostname, but the DNS module failed to resolve the remote address on 
   the first try.  This, for example, would occur if you powered up your board 
   and tried to connect to a remote server before the Ethernet cable was 
   attached.  Once the Ethernet cable was attached, the socket would attempt to 
   resolve and connect to a garbage address.  The Internet Radio application 
   would sometimes not begin playing the default station upon power up because 
   of this problem.
2. Set SEQ.ACK = 0 for outbound TCP SYN packets.  This fixes a connection 
   compatibility problem with certain paranoid TCP/IP stacks that would validate 
   this field even though the ACK flag was clear.  This problem would previously 
   cause the Microchip TCP/IP stack to be unable to connect client-mode TCP 
   sockets to certain rare servers/services.  Thanks go to Jean LE TUTOUR for 
   finding one of these problem servers.
3. MPFSOpen() and MPFSOpenROM() for MPFS2 could leak a file handle if a name 
   hash matched but no complete file name did.  This has been corrected to 
   prevent potential DOS attacks on the HTTP2 web server.  Thanks to David Tan 
   on the Microchip Ethernet formus for identifying this issue.
4. Fixed a bug in MPFS2.1 that caused compile errors when MPFS Classic images
   were generated for ASM30 containing files whose length was either zero or
   a multiple of 12.
5. Fixed an issue in HTTPPostConfig() that caused it to ignore the flag that
   was set when invalid IP address input was detected.  This issue only affects 
   the example configuration page and only exists in v4.50 (prior versions 
   functioned correctly).  Also corrected an issue where user input could 
   potentially overflow into part of the shadow AppConfig in the same function.
   Thanks to prinz3nroll3 on the Microchip Ethernet forums for identifying 
   both of these issues.
6. Implemented Explorer 16 development board 5V LCD errata workaround to 
   LCDBlocking.c.  This corrects the A/D converter from returning erratic 
   readings on certain Explorer 16 boards.  LCD I/O pins are now continuously 
   driven by the microcontroller instead of going high impedance when idle.
7. Fixed a critical ENC28J60 revision B7 errata workaround problem in the 
   ENC28J60.c, MACFlush() function.  Previously, the code was checking for an 
   EREVID register value of 0x07 for silicon revision B7.  This was incorrect.  
   Silicon revision B7 actually has an EREVID value of 0x06.  Note that this 
   problem was caused by an incorrect EREVID value published in DS80349A, the B7 
   silicon errata documentation.  Make sure to use DS80349B or later.

Known Problems:
1. Telnet server module does not implement a lot of Telnet functions.  As a 
   result, it will likely not display correctly or work at all with some Telnet 
   clients.  The server was tested with the Microsoft telnet.exe utility which 
   is provided with Microsoft Windows.
2. If the DHCP client and DHCP server are used at the same time and you connect 
   two similar boards to each other (ex: two PICDEM.net 2 boards connected via 
   a crossover cable), a race condition can occur where both nodes will disable 
   their DHCP server and neither board will get a successful DHCP lease.  If 
   this unlikely scenario occurs, as a work around, simply reset one of the 
   boards to reenable it's DHCP server.
3. HI-TECH PICC-18 projects may not compile when targeting the external 
   ENC28J60 chip on the PICDEM.net 2 development board (instead of the 
   internal Ethernet controller).  This problem only applies when a 
   PIC18F97J60 family part is the target.  I.e. it compiles correctly for the 
   HPC_EXPLORER + Ethernet PICtail.
4. MAC.h RXSIZE precompiler test for proper range doesn't work.  This is not a 
   functional problem, just a compile-time configuration test.  Ensure that you don't 
   over allocate TCP_ETH_RAM_SIZE or MAX_HTTP_CONNECTIONS.
5. HI-TECH PICC-18 STD 9.51PL1 cannot compile DynDNS.c.  It raises an 
   "inconsistent type" error while trying to perform a ROM pointer to integer 
   cast.  The older 9.50PL3 compiler release is required to compile this file.
6. HI-TECH PICC-18 STD 9.50PL3 does not initialize several static variables 
   correctly on reset.  This behavior breaks many stack modules in the 
   TCPIP Demo App and TCPIP WebVend App projects.  Additionally, string 
   printing functions do not work correctly, so the supplied 
   "TCPIP Demo App-HITECHPICC18 PICDEMNET2 18F97J60.hex" and "TCPIP WebVend 
   App-HITECHPICC18 PICDEMNET2 18F97J60.hex" files may not correctly print the 
   board's DHCP assigned IP address on the board's LCD (if present) and UART.  To 
   avoid these severe problems, use the Microchip MPLAB C Compiler for PIC18 MCUs.  
   A free student edition can be downloaded from http://www.microchip.com/c18.

********
v4.50 		02 June 2008
********
IMPORTANT NOTE: You must use MPLAB 8.10 or higher to successfully open the 
   MPLAB projects.  Also, ensure that the latest C compiler is used.  This 
   release was tested against MPLAB C Compiler for PIC18 MCUs version 3.20, 
   MPLAB C Compiler for PIC24 MCUs and dsPIC DSCs version 3.10, MPLAB C 
   Compiler for PIC32 MCUs version 1.01, and HI-TECH PICC-18 version 
   9.50PL3 (STD).  Earlier compilers may not be able to compile this TCP/IP 
   stack release.

Changes:
1. Added SSL 3.0 client capabilities, including SMTP over SSL.  The SSL
   modules supports up to 1024-bit RSA handshakes and 128-bit ARCFOUR 
   bulk encryption.  This can be demonstrated using the SMTP client.  SSL
   server support is functional, but a key generation utility is not yet 
   provided and support over HTTPS is not yet reliable with all browsers.
   IMPORTANT: Encryption software is covered by US Export Control law, so
   it is not directly downloadable from the Microchip website.  To use the 
   encryption modules, you must order SW300052 from microchipDIRECT 
   [ https://www.microchipdirect.com/ ] and install the required libraries.
2. Added Berkeley Sockets Distribution (BSD) API translation layer.  You can 
   now call the well know Berkeley APIs instead of or in addition to the 
   Microchip specific APIs.  To use this new functionality, define 
   STACK_USE_BERKELEY_API and configure BSD_SOCKET_COUNT in TCPIPConfig.h.  
   Three new source code demos are provided to demonstrate this API: 
   BerkeleyTCPClientDemo.c, BerkeleyTCPServerDemo.c, and 
   BerkeleyUDPClientDemo.c.  The TCP client demo is identical to the 
   GenericTCPClient.c demo, but implemented using Berkeley Sockets.  The UDP 
   client demo is similarly identical to the SNTP.c client.  The TCP server 
   demo listens on TCP port 9764 and will echo any traffic received back to the 
   sender.  It allows up to 3 simultaneous connections when there are an 
   adequate number of sockets defined in the TCPSocketInitializer[] array in 
   TCPIPConfig.h.
3. Added support for Dynamic DNS services.  See the Dynamic DNS Client module in 
   the TCP/IP Stack Help for details.  Presently, dyndns.org, dyndns.com, 
   no-ip.com, and dns-o-matic.com are supported.
4. Added the Microchip TCP/IP Configuration Wizard to the Utilities folder, 
   facilitating easier configuration of the TCP/IP Stack through a 
   graphical application.
5. Restructured TCPIPConfig.h to remove rule-enforcement logic, placing the 
   removed sections in TCPIP.h.  Many other project structure changes were also 
   made to clean up the general distribution appearance.
6. Increased DHCP Server default lease duration to 60 seconds instead of 15 
   seconds.  Some computers were losing their IP lease before performing a renew 
   operation with only a 15 second lease.
7. Removed CLOCK_FREQ, INSTR_FREQ, and PERIPHERAL_FREQ macro definitions.  
   GetSystemClock(), GetInstructionClock(), and GetPeripheralClock() now return 
   these respective values.  This change was made for compatibility with other 
   Microchip software libraries.
8. Added TCP Fast Retransmission capability.  Whenever three duplicate ACK 
   packets arrive, the stack will now immediately perform a retransmit 
   operation.  This greatly improves recovery latency whenever the network 
   loses a packet for applications that stream TX data using TCP.
9. Improved TCP Keep Alive mechanism to automatically close TCP sockets which 
   do not receive any keep-alive responses for TCP_MAX_UNACKED_KEEP_ALIVES 
   (default 6) times.  This means that, by default, any connection that 
   catastrophically breaks without notifying us (ex: user unplugs cable, 
   Internet connection goes down, etc.) will time out and automatically close 
   after 60 seconds (TCP_MAX_UNACKED_KEEP_ALIVES * TCP_KEEP_ALIVE_TIMEOUT).  
   Server oriented sockets will return to the listening state.  Client oriented 
   sockets will close, but the TCP_SOCKET handle will continue to remain valid 
   until the application calls TCPDisconnect().  Applications can check if the 
   socket became disconnected and reset by calling TCPWasReset() or 
   TCPIsConnected().  Note that this keep alive implementation will only close 
   sockets that are broken (remote node is not responding to TCP requests).  It
   will not close or otherwise interfere with idle connections in which the 
   application is not transmitting or receiving data and wishes to keep the 
   connection open.
10.Added a TCP RX SYN queue of depth TCP_SYN_QUEUE_MAX_ENTRIES (default 3).  
   This queue automatically saves incoming SYN packets destined for a local 
   server port which is already connected to a different client.  When the 
   client disconnects, the SYN data is pulled out of the queue and the socket 
   immediately attempts to connect to the next client.  This improves connect 
   time performance since the remote client no longer has to retransmit the 
   SYN request if it was unserviceable the first time around.  This is most 
   apparent with the HTTP/HTTP2 servers which previously performed poorly 
   with certain modern web browsers which attempt to open many simultaneous 
   connections to the web server, such as Mozilla Firefox 3 beta 5 and Apple 
   Safari 3.1.  Entries in the queue automatically time out after 
   TCP_SYN_QUEUE_TIMEOUT (default 3 seconds) so as to prevent the queue from 
   filling up permanently if several connection requests arrive for a service 
   that is in use and will not be available for an extended period.
11.Modified the structure of the MPFS2 FAT (now known as MPFS2.1) to include 
   name hashes first.  This speeds up opening files by 25%, and makes opening 
   index files nearly instant.
12.Updated the MPFS2 Utility.  MPFS2.1 now supports the new FAT structure and 
   provides a cleaner interface.  It also writes images to disk as they are 
   created, which eliminates the IndexOutOfBounds exceptions some users had 
   reported.  Finally, uploads are now truly multi-threaded.
13.Source code to the MPFS2.exe PC utility is now released.  Find it in the 
   Microchip Solutions\Microchip\TCPIP Stack\Utilities\Source\MPFS21 folder.  This 
   project is designed to compile with Microsoft Visual C# 2008 Express Edition.
14.Added support for SST25VFxxxB serial flash parts in 2, 4, 8, 16, and 32Mbit
   densities.  These parts can be used to replace EEPROMs for storing MPFS
   images (both versions) and custom data.
15.Added HTTPReadPostName, HTTPReadPostValue, and HTTPReadPostPair functions to 
   facilitate easier processing of data arriving via POST.
16.Split HTTPAuthenticate API into separate functions: HTTPNeedsAuth and 
   HTTPCheckAuth.  This function was already split internally, and didn't 
   make sense as a single API.
17.Updated DHCP client to close its UDP socket when idle (bound state) to save 
   a small amount of resources.
18.Removed LED_IO macro from all hardware profiles because it is not suitable 
   for use on certain hardware platforms that have non-contiguous LEDs or 
   reversed bit ordering.  Use the new LED_GET() and LED_PUT(val) macros to read 
   and write to all of the LEDs at once.
19.Added Ethernet Hash Table Calculator.exe to the Utilities folder and start menu.
   This tool will calculate the correct bit that you must set in the EHT0-EHT7 
   registers on the ENC28J60 and PIC18F97J60 family devices for using the Hash 
   Table RX filter.  This is useful only for fixed MAC addresses known at design 
   time.  For addresses that are known at run time, use the SetRXHashTableEntry() 
   function in the ENC28J60.c or ETH97J60.c files to set the correct EHT0-EHT7 bit.

Fixes:
1. Fixed a buffer overflow data corruption issue in the FTP module that arises 
   when too many parameters were passed on the command line.
2. Moved TCPWasReset checking in HTTP2 to execute for every socket on every
   loop.  Previously, it would only execute when a socket reconnected, which 
   caused the RX buffer to not resize until after data was received.  Some 
   platforms (notably FF2 on Ubuntu) would stall if the initial advertised RX 
   window was too small, and this change corrects that issue.
3. Updated SendSystemReset() and MACInit() initialization routine in ENC28J60.c.  
   Previously, if the ENC28J60 was placed into sleep mode by calling 
   MACPowerDown(), the SendSystemReset() command would not work anymore.  This 
   would leave the ENC28J60 in power down if the host PIC was ever reset.  
   SendSystemReset() should work for all conditions with this update.
   Thanks go to Rob Haverkort on the Microchip Ethernet forum for identifying 
   this problem.
4. Fixed an alignment bug in HTTP2 that caused redirects to fail when the MPFS2
   image was stored in Flash program memory.  Thanks to Todd Boaz on the
   Microchip Ethernet forum for identifying this bug, and Chen Qu for posting
   a solution.
5. Fixed SNTP client from losing accuracy if you called SNTPGetUTCSeconds() 
   10s of thousands of times since the last server synchronization.  Thanks go to
   "pic123" on the Microchip Ethernet forum for noticing this error.
6. Fixed a TickGet*() API problem where the returned tick value could be off by 64K 
   ticks occasionally on PIC24, dsPIC30/33, and PIC32 processors.  This bug was 
   previously fixed in stack versions 4.13 and 4.16, but it was unintentionally 
   recreated in 4.18 due to PIC32 changes.
7. Fixed UART2TCPBridge module from failing to connect to a remote server when 
   USE_REMOTE_TCP_SERVER was defined.
8. Fixed an issue that prevented SNMP SETs on 16 and 32 bit parts when using
   MPFS2.  Thanks go to Milena K on the Microchip Ethernet forum for identifying
   this problem.
9. Fixed a rare buffer corruption issue that could occur with UDP if TCP was also 
   enabled.
10.Fixed a Tick rollover error in HTTP2.  Thanks go to Paul Bixel on the Microchip
   Ethernet forum for identifying this problem.
11.Fixed an MPFS2 bug in which an excessive value to MPFS_SEEK_REWIND may have 
   failed to return an error.  Thanks go to Paul Bixel on the Microchip Ethernet 
   forum for identifying this problem as well.
12.SMTP Client now sends EHLO when using authentication.  Previously, the HELO
   command was used, even with authentication enabled.  Using HELO with 
   authentication creates incompatibilities with certain SMTP servers.
13.Improved Internet Bootloader robustness by retransmitting ACKs in response to 
   data retransmissions by the remote sending node.  Previously, if an ACK packet 
   was lost before reaching the sending node, the TFTP upload would fail and need 
   to be restarted.  Thanks go to "coolvibe" Dave Collier on the Microchip Ethernet
   forum for identifying this behavior.
14.Fixed TFTP Internet Bootloader from not being accessible from Linux TFTP clients 
   which were setting the IP header "Don't Fragment" flag bit.
15.Changed TCP so that unsent data that is automatically flushed by the 
   TCP_AUTO_TRANSMIT_TIMEOUT_VAL timer includes the PSH flag.  This improves GUI 
   responsiveness for certain applications which rely on this automatic flush 
   feature, such as the UART2TCPBridge module.
16.Fixed TCP socket loss issue which could occur if the TCP TX FIFO size was 
   greater than 536 bytes (TCP_MAX_SEG_SIZE).  Before the fix, the socket 
   would have gotten tied up indefinitely performing retransmissions every 1.0 
   seconds without detecting that the remote node was disconnected.
17.Fixed TCP socket hang issue that would occur if the PIC sent out a FIN and the 
   remote node never responded with a corresponding FIN.  The socket would have 
   gotten stuck indefinitely in the TCP_FIN_WAIT_2 state.  Thanks go to Mr. Kyle 
   Strickland with AW North Carolina for identifying this bug.
18.Fixed UDPSetRxBuffer() function from not working if it was called before having 
   called UDPGet() or UDPGetArray() at least once.
19.Fixed an offset error of +2 milliseconds being returned from 
   TickConvertToMilliseconds().  Thanks go to Andrés ("saturn") on the Microchip 
   Ethernet forum for finding this error.  Note that due to integer truncation 
   during division, this function can be off by 0.2% or so, depending on the value 
   returned by GetPeripheralClock().
20.Updated DelayMs() macro for MPLAB C Compiler for PIC18s to work correctly 
   when a large parameter was given.  You should now be able to delay between 
   0 and 65535 milliseconds across all supported compilers without ending up 
   with an unexpectedly short delay.

Known Problems:
1. Telnet server module does not implement a lot of Telnet functions.  As a 
   result, it will likely not display correctly or work at all with some Telnet 
   clients.  The server was tested with the Microsoft telnet.exe utility which 
   is provided with Microsoft Windows.
2. If the DHCP client and DHCP server are used at the same time and you connect 
   two similar boards to each other (ex: two PICDEM.net 2 boards connected via 
   a crossover cable), a race condition can occur where both nodes will disable 
   their DHCP server and neither board will get a successful DHCP lease.  If 
   this unlikely scenario occurs, as a work around, simply reset one of the 
   boards to reenable it's DHCP server.
3. HI-TECH PICC-18 projects may not compile when targeting the external 
   ENC28J60 chip on the PICDEM.net 2 development board (instead of the 
   internal Ethernet controller).  This problem only applies when a 
   PIC18F97J60 family part is the target.  I.e. it compiles correctly for the 
   HPC_EXPLORER + Ethernet PICtail.
4. MAC.h RXSIZE precompiler test for proper range doesn't work.  This is not a 
   functional problem, just a compile-time configuration test.  Ensure that you don't 
   over allocate TCP_ETH_RAM_SIZE or MAX_HTTP_CONNECTIONS.
5. HI-TECH PICC-18 STD 9.51PL1 cannot compile DynDNS.c.  It raises an 
   "inconsistent type" error while trying to perform a ROM pointer to integer 
   cast.  The older 9.50PL3 compiler release is required to compile this file.
6. HI-TECH PICC-18 STD 9.50PL3 does not initialize several static variables 
   correctly on reset.  This behavior breaks many stack modules in the 
   TCPIP Demo App and TCPIP WebVend App projects.  Additionally, string 
   printing functions do not work correctly, so the supplied 
   "TCPIP Demo App-HITECHPICC18 PICDEMNET2 18F97J60.hex" and "TCPIP WebVend 
   App-HITECHPICC18 PICDEMNET2 18F97J60.hex" files may not correctly print the 
   board's DHCP assigned IP address on the board's LCD (if present) and UART.  To 
   avoid these severe problems, use the Microchip MPLAB C Compiler for PIC18 MCUs.  
   A free student edition can be downloaded from http://www.microchip.com/c18.

********
v4.18 		28 November 2007
********
Changes:
1. Added C32 and PIC32MX support.  Some things were cleaned up in the process.
2. Removed linker scripts from C30 MPLAB projects.  MPLAB IDE 8.00 
   can automatically select the correct linker script for 16-bit and 32-bit 
   products.
3. Updated TCPPerformanceTest.c module.  Now it automatically calculates the TX 
   throughput and displays it for you.  Also, there is now an RX throughput 
   testing mode, which listens on a separate TCP socket (port 9763) when a TCP 
   socket of type TCP_PURPOSE_TCP_PERFORMANCE_RX is allocated in TCPIPConfig.h.  
   The RX socket is by default not enabled to save memory, so you must create a 
   TCP_PURPOSE_TCP_PERFORMANCE_RX socket in TCPIPConfig.h and ensure that enough 
   memory is allocated to accommodate it to test the RX performance test.  When 
   connected to port 9763, send a large amount of data and the PIC 
   microcontroller will send back a count of how many bytes were received per 
   second.  
4. UDPPerformanceTest.c module now transmits 1024 packets on start up and then 
   stops to prevent continually broadcast flooding your network.  To transmit 
   more packets after 1024 is reached, hold down BUTTON3 (left-most button on 
   most boards).
5. Significantly improved the speed of the MD5 and SHA-1 functions.  Gains for 
   the 8-bit compilers were 50-75%, while 16-bit parts saw more modest
   improvements (~10%).
6. Reimplemented TCP_CLOSE_WAIT TCP state ("CLOSE WAIT" in RFC793).  Now, TCP 
   sockets that receive a FIN from the remote node will hold off transmitting 
   a FIN back to the remote node until the TCP_CLOSE_WAIT_TIMEOUT (defined at 
   the top of TCP.c) elapses or immediately when the application calls the 
   TCPDisconnect() function.  This makes it possible for the application to 
   transmit a response back to the remote node before the socket becomes closed 
   on our end.  Similarly, it simplifies application usage of the last RX bytes 
   received as these bytes are now assured to still be in the RX FIFO for at 
   least TCP_CLOSE_WAIT_TIMEOUT seconds.  TCP_CLOSE_WAIT_TIMEOUT defaults to 
   200ms in this stack version.
7. Pushed the SNTP requery on failure timeout up some.  It was ~14 seconds and 
   is now ~20 seconds.
8. Added TFTPOpenROMFile() API to complement TFTPOpenFile() when using PIC18 
   products.
9. Added a fourth parameter to newAJAXCommand() in mchp.js, allowing data to be
   POSTed along with the AJAX request.
10.Deprecated the TCP Loopback functions, which includes TCPOpenLoopback, 
   TCPCloseLoopback, TCPIsLoopback, TCPInject, and TCPSteal.  These functions
   were added in 4.10 for future SSL support, but have since become 
   unnecessary.  They are of limited usefulness, and so are being removed to save
   code space.  The functions are still available in this version, but will 
   be removed in the next release.
11.Added SMTPClient.ServerPort field to the SMTP API.  This allows the remote 
   server port number to be specified dynamically at run time instead of being 
   hard coded to the SMTP_PORT value defined at the top of SMTP.c.  SMTP_PORT is 
   now only a default.
12.Added web interface to the SMTP module in the TCPIP Demo App applications.  
   You can now configure the SMTP module and send emails directly from within 
   your web browser.  The HTTPPostEmail() function in CustomHTTPApp.c also 
   demonstrates how to send MIME encoded attachments in emails.  The default demo 
   will send button states, LED states, and the current potentiometer reading as 
   a CSV file attached to the email.
13.Changed SMTPDemo() in MainDemo.c to trigger on BUTTON2 and BUTTON3 
   simultaneously held down instead of BUTTON0 only.

Fixes:
1. Fixed an ENC28J60.c MACGetArray() bug which would overwrite one byte of memory 
   at address 0xFFFFFFFF if you provided NULL for the destination address pointer.
2. Fixed an MPFS2.c MPFSGet() bug which would overwrite memory address 0x00000000 
   if a NULL pointer was provided as the destination.
3. Fixed a bug in the HTTP2 server accessing incorrect sockets if an inadequate 
   number of sockets were available on POR.
4. Fixed Internet Bootloader project from failing with a timeout if an ARP packet 
   arrived during the Erase/Write operation.
5. Fixed DHCP client RFC non-compliance where it would send the ciaddr field in 
   the initial SELECTING state.  Also, in the RENEWING state, the Requested IP 
   Address option was being sent, which is illegal.  These changes may fix 
   compatibility problems with certain DHCP servers.
6. Fixed TFTP Client's TFTPCloseFile() function from sending data using a wrong 
   UDP socket if StackTsk() was called after TFTPIsFileOpened() was last called.
7. Added two zero bytes to the ICMP echo request payload to improve compatibility 
   with some buggy NAT routers.

Known Problems:
1. Telnet server module does not implement a lot of Telnet functions.  As a 
   result, it will likely not display correctly or work at all with some Telnet 
   clients.  The server was tested with the Microsoft telnet.exe utility which 
   is provided with Microsoft Windows.
2. If the DHCP client and DHCP server are used at the same time and you connect 
   two similar boards to each other (ex: two PICDEM.net 2 boards connected via 
   a crossover cable), a race condition can occur where both nodes will disable 
   their DHCP server and neither board will get a successful DHCP lease.  If 
   this unlikely scenario occurs, as a work around, simply reset one of the 
   boards to reenable it's DHCP server.
3. HI-TECH PICC-18 projects may not compile when targeting the external 
   ENC28J60 chip on the PICDEM.net 2 development board (instead of the 
   internal Ethernet controller).  This problem only applies when a 
   PIC18F97J60 family part is the target.  I.e. it compiles correctly for the 
   HPC_EXPLORER + Ethernet PICtail.
4. MAC.h RXSIZE precompiler test for proper range doesn't work.  This is not a 
   functional problem, just a compile-time configuration test.  Ensure that you don't 
   over allocate TCP_ETH_RAM_SIZE or MAX_HTTP_CONNECTIONS.

********
v4.16 		06 November 2007
********
Changes:
1. Added Internet Radio application.  This is a TCP client application which 
   downloads streaming MP3 audio from a Shoutcast server and then plays it back to 
   stereo earphones via a VLSI VS1011 audio decoder.
2. Added SPIRAM.c module.  This module is intended for interfacing to an AMI 
   Semiconductor N256S0830HDA SPI RAM chip.  The TCP module can now interface 
   directly to this SPIRAM module to store TCP socket FIFO buffers and other TCB 
   data in the external RAM.
3. Added TCP_OPTIMIZE_FOR_SIZE compile time configuration macro to TCP.c file.  When 
   optimizing for small code size, the TCP module ROM footprint shrinks up to 6KB, 
   but performance may slow down on some processors (namely PIC18s, where the 
   penalty is approximately 15%).
4. Added USE_EEPROM_25LC1024 compile time configuration macro to TCPIPConfig.h.  
   Enable this definition if you are storing your MPFS[2] on a 1Mbit 25LC1024 or 
   similar EEPROM device that uses 24-bit addressing and a 256 byte write page size.
5. Changed LCDBlocking.c module initialization code.  It should now be possible to 
   use 4-bit mode on certain "unusual" LCD controllers, like the Samsung S6A0032.  
   Most PICDEM.net 2 and Explorer 16 boards use an LCD with this controller.
6. SNTP client now attempts to requery the SNTP server about every 14 seconds if the 
   last query attempt fails.  This allows the internal time value to become valid 
   quickly should the board be powered up before an Ethernet cable is attached or if 
   the DHCP client doesn't obtain an IP address quickly enough.  Previously, it would 
   take up to 10 minutes after plugging the Ethernet cable in to get a correct time 
   value from the SNTP server.
7. Added UDP_USE_TX_CHECKSUM compile time configuration macro to TCPIPConfig.h.  
   When enabled, all UDP packets will have a correct UDP checksum computed and 
   inserted into the UDP header of outbound packets.  If you do not define this 
   macro, the UDP checksum will be disabled (left as 0x0000), which is how previous 
   stack versions operated.  Note that enabling checksum generation cuts your 
   maximum UDP TX throughput by nearly half due to the required computations.
8. Substantially changed TCP socket RX and TX FIFO allocation.  Now, sockets can be 
   stored either in Ethernet RAM, PIC RAM, or external (SPI) RAM.  Previously, 
   sockets could only be allocated in Ethernet RAM, which was not scalable.
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

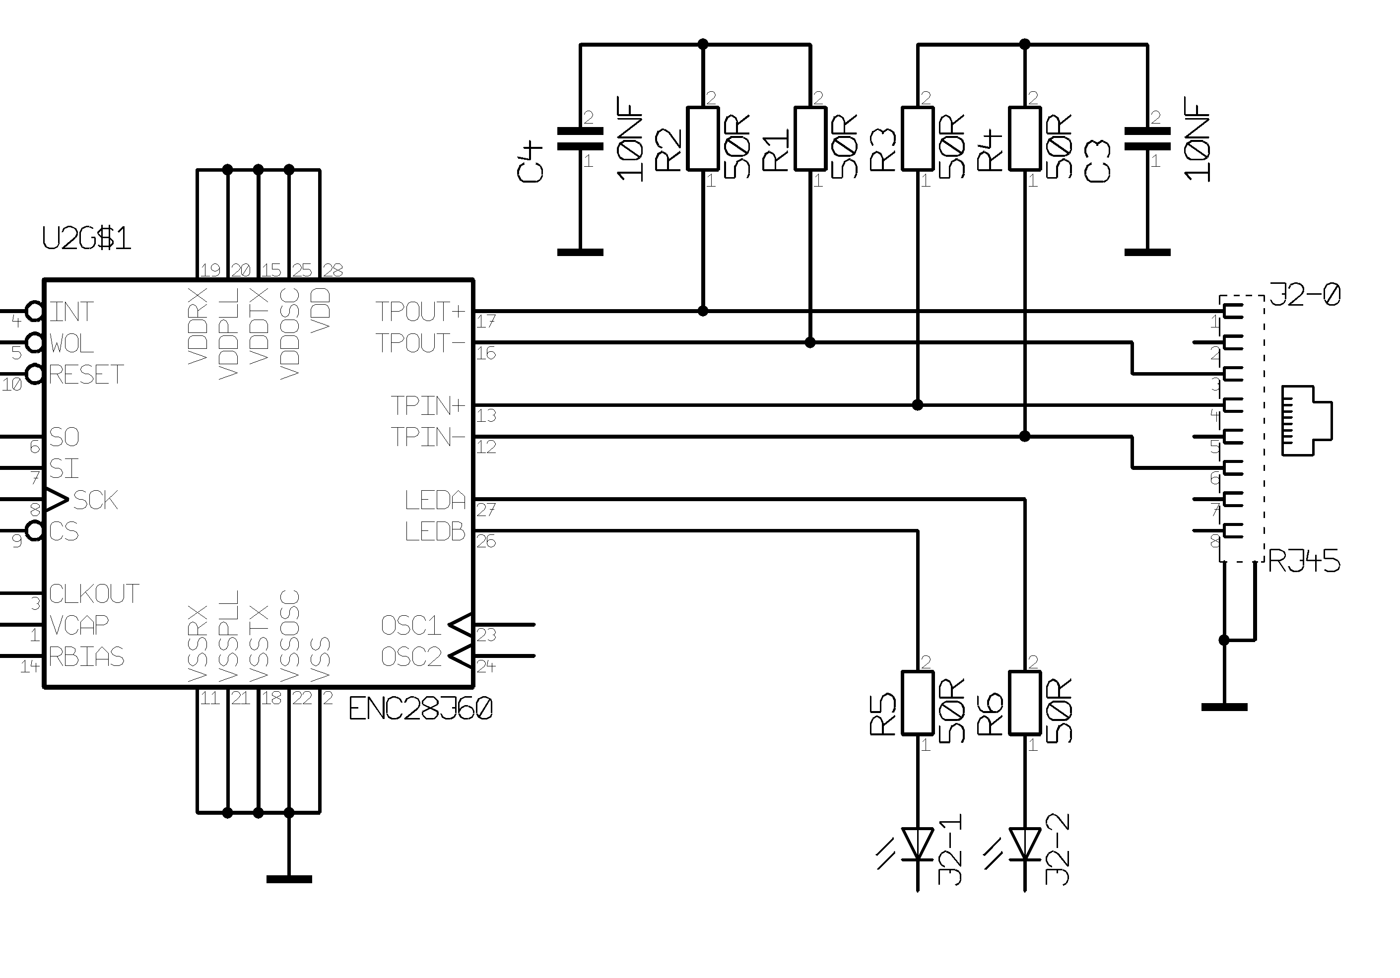
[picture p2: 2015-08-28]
docs/MagJack.png

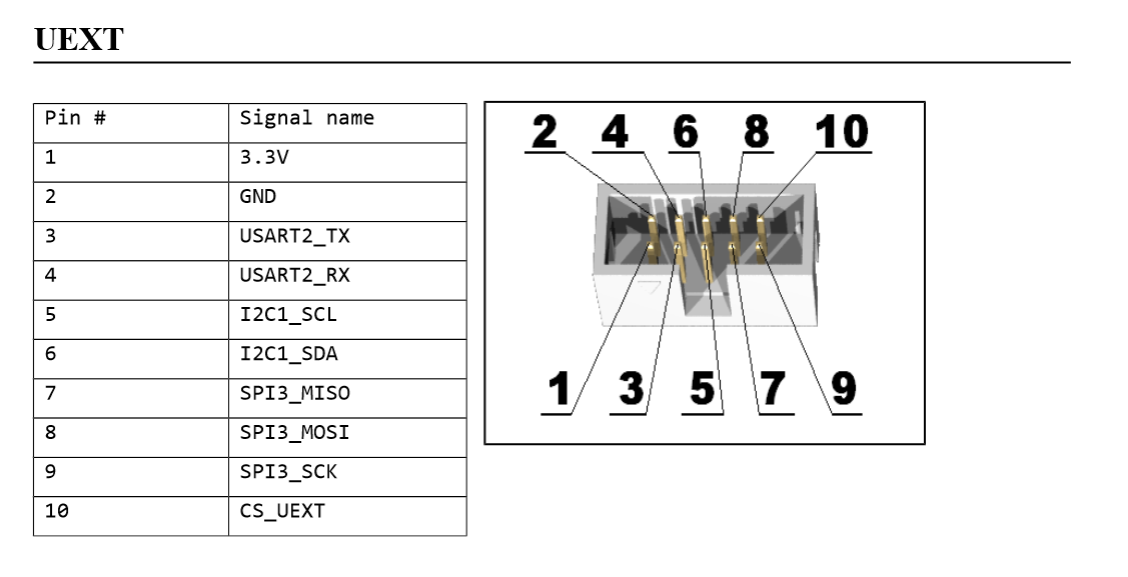
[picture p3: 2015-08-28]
docs/UEXT.png

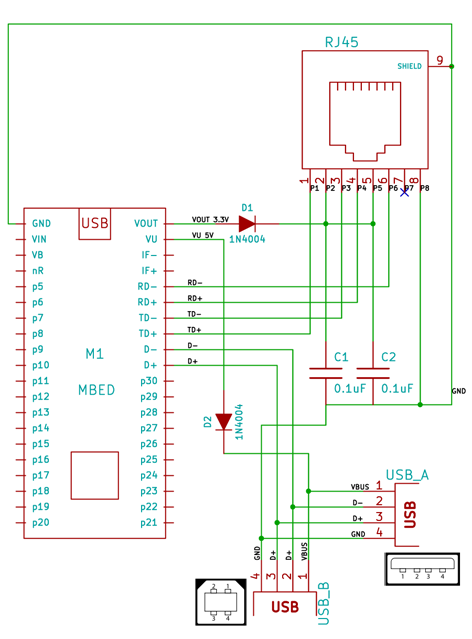
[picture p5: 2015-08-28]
docs/schem.png

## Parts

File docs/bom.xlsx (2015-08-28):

 |  |  |  | Dollarkrs | 6.3
# | Component | Kommentar | Supplier | Unit Price | Sum
2 | MC34063ADGOS-ND | Regulator | Digikey | 0.84 | 1.68
1 | PIC18F67J60-I/PT-ND | uP | Digikey | 5.8 | 5.8
1 | 24AA02E48T-I/OTCT-ND | Ethernet MAC address | Digikey | 0.34 | 0.34
1 | RJ-45 connector RJP-003TC1 | RJ45 + Magnetics | Digitale-Analoge-Componenten-West | 2.94 | 2.94
1 | AT45DB011D-SH-B-ND | 1 Mbit memory | DigiKey | 0.86 | 0.86
1 | MCP2515-I/SO-ND | CAN controler | DigiKey | 1.98 | 1.98
1 | Kretskort (~120 kronor) |  | makepcb | 2.28 | 2.28
1 | Låda (~70 kronor) |  | SVENSKA HELAG AB | 10.5 | 10.5
 |  |  |  |  | 0
 |  |  |  |  | 0
 |  |  |  |  | 0
 |  |  |  |  | 0
 |  |  |  |  | 0
 |  |  |  |  | 0
 |  |  |  |  | 0
 |  |  |  |  | 0
 |  |  |  |  | 0
 |  |  |  |  | 0
 |  |  |  |  | 0
 |  |  |  |  | 0
 |  |  |  |  | 0
 |  |  |  |  | 0
 |  |  |  |  | 0
 |  |  |  |  | 0
 |  |  |  |  | 0
 |  |  |  |  | 0
 |  |  |  |  | 0
 |  |  |  |  | 0
 |  |  |  |  | 0
 |  |  |  |  | 0
 |  |  |  |  | 0
 |  |  |  |  | 26.38 | 166.194

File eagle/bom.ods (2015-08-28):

Partl | ist exported from C: | /Users/akhe/Docum | ents/development/ | hardware_zeus/Ethernet/ethernet modul | e/snö/schematics/snow_rev | _A.sch at | 2011-09-30 11:38:49
Part | Value | Device | Package | Description | Description | Supplier | Partnumber | Price
C1 | 12pF | C-EUC0805 | C0805 | CAPACITOR, European symbol | 12pF Cheramic capacitor | Bejoken | 522417 | 0,11
C2 | 12pF | C-EUC0805 | C0805 | CAPACITOR, European symbol | 12pF Cheramic capacitor | Bejoken | 522417 | 0,11
C3 | 100n | C-EUC0805 | C0805 | CAPACITOR, European symbol | 100nF Cheramic capacitor | Bejoken | 522526 | 0,07
C4 | 220nF | C-EUC0805 | C0805 | CAPACITOR, European symbol | Capacitor | Digikey | 587-1306-2-ND | 0,14
C5 | 100n | C-EUC0805 | C0805 | CAPACITOR, European symbol | 100nF Cheramic capacitor | Bejoken | 522526 | 0,07
C6 | 100n | C-EUC0805 | C0805 | CAPACITOR, European symbol | 100nF Cheramic capacitor | Bejoken | 522526 | 0,07
C7 | 100n | C-EUC0805 | C0805 | CAPACITOR, European symbol | 100nF Cheramic capacitor | Bejoken | 522526 | 0,07
C8 | 100n | C-EUC0805 | C0805 | CAPACITOR, European symbol | 100nF Cheramic capacitor | Bejoken | 522526 | 0,07
C9 | 100n | C-EUC0805 | C0805 | CAPACITOR, European symbol | 100nF Cheramic capacitor | Bejoken | 522526 | 0,07
C10 | 100n | C-EUC0805 | C0805 | CAPACITOR, European symbol | 100nF Cheramic capacitor | Bejoken | 522526 | 0,07
C11 | 10uF/6.3V | CPOL-EUSMCP | SMC_P | POLARIZED CAPACITOR, European symbol | Capacitor | Digikey | 493-2328-1-nd | 3,6
C12 | 100n | C-EUC0805 | C0805 | CAPACITOR, European symbol | 100nF Cheramic capacitor | Bejoken | 522526 | 0,07
C13 | 22pF | C-EUC0805 | C0805 | CAPACITOR, European symbol | 22pF Cheramic capacitor | Bejoken | 522423 | 0,11
C14 | 22pF | C-EUC0805 | C0805 | CAPACITOR, European symbol | 22pF Cheramic capacitor | Bejoken | 522423 | 0,11
C15 | 100n | C-EUC0805 | C0805 | CAPACITOR, European symbol | 100nF Cheramic capacitor | Bejoken | 522526 | 0,07
C16 | 4.7nF | C-EUC0805 | C0805 | CAPACITOR, European symbol | 4.7nF Cheramic capacitor | Bejoken | 522508 | 0,05
C17 | 4.7nF | C-EUC0805 | C0805 | CAPACITOR, European symbol | 4.7nF Cheramic capacitor | Bejoken | 522508 | 0,05
C18 | 2.2UF 50V | C-EUC2012 | C2012 | CAPACITOR, European symbol | Capacity | Digikey | 445-3464-1-ND | 2,4
C19 | 220uF/10V | CPOL-EUSMCC | SMC_C | POLARIZED CAPACITOR, European symbol | Capacitor SMD | Digikey | 399-5168-1-nd | 12,56
C20 | 220uF/10V | CPOL-EUSMCC | SMC_C | POLARIZED CAPACITOR, European symbol | Capacitor SMD | Digikey | 399-5168-1-nd | 12,56
C21 | 100nF | C-EUC0805 | C0805 | CAPACITOR, European symbol |  |  | 522526 | 0,07
C22 | 100nF | C-EUC0805 | C0805 | CAPACITOR, European symbol |  |  | 522526 | 0,07
C23 | 100n | C-EUC0805 | C0805 | CAPACITOR, European symbol | 100nF Cheramic capacitor | Bejoken | 522526 | 0,07
D1 | LED Yellow | LED_2012 | C2012 |  | LED Gul | Digikey | 475-2555-1-ND | 1,28
D2 | LED Green | LED_2012 | C2012 |  | Grön LED | Digikey | 475-1410-1-nd | 0,88
D3 | LED Röd | LED_2012 | C2012 |  | Röd LED | Digikey | 475-1415-1-ND | 0,88
D5 | 1N5819 | 1N5819 | SOD-123 |  | Schotty diod | Digikey | 1n5819hw-fdict-nd | 3,84
IC1 | PIC18F67J60 | PIC18F67J60 | TQFP64-10X10 |  | Microprocessor | Digikey | pic18f67j60-i/pt-nd | 46,4
IC2 | AT45DB011D | AT45DB011D | SOP8 |  | Flash memory | Digikey | at45db011d-sh-b-nd | 6,88
IC4 | BD9001F | BD9001F | SOP8 |  | Swithing regulator | Digikey | BD9001F-E2CT-ND | 39,84
JP2 |  | FE12-2 | FE12-2 | FEMALE HEADER |  | Digikey | SAM1212-50-ND | 6,18
JP4 |  | MA06-1 | MA06-1 | PIN HEADER | Digikey |  | SAM1035-50-ND | 0,33
L1 | NR10050T470M | NR10050T470M | NR10050T470M |  | Inductance | Digikey | 587-1700-1-ND | 7,52
L2 | FERRITE-BEAD | FERRITE-BEAD | 805 |  | Ferrite | Digikey | 445-1568-1-nd | 2,88
R1 | 1M | R-EU_M0805 | M0805 | RESISTOR, European symbol | Resistor | Bejoken | 454742 | 0,01
R2 | 10k | R-EU_M0805 | M0805 | RESISTOR, European symbol | Resistor | Bejoken | 454676 | 0,01
R3 | 330 | R-EU_M0805 | M0805 | RESISTOR, European symbol | Resistor | Bejoken | 454636 | 0,01
R4 | 270 1% | R-EU_M0805 | M0805 | RESISTOR, European symbol | Resistor | Bejoken | 454634 | 0,01
R5 | 2K 1% | R-EU_M0805 | M0805 | RESISTOR, European symbol | Resistor | Bejoken | 454659 | 0,01
R6 | 330 | R-EU_M0805 | M0805 | RESISTOR, European symbol | Resistor | Bejoken | 454636 | 0,01
R7 | 330 | R-EU_M0805 | M0805 | RESISTOR, European symbol | Resistor | Bejoken | 454636 | 0,01
R8 | 330 | R-EU_M0805 | M0805 | RESISTOR, European symbol | Resistor | Bejoken | 454636 | 0,01
R9 | 330 | R-EU_M0805 | M0805 | RESISTOR, European symbol | Resistor | Bejoken | 454636 | 0,01
R10 | 100k | R-EU_M0805 | M0805 | RESISTOR, European symbol | Resistor | Bejoken | 454704 | 0,01
R11 | 150k | R-EU_M0805 | M0805 | RESISTOR, European symbol | Resistor | Bejoken | 454710 | 0,01
R12 | 150k | R-EU_M0805 | M0805 | RESISTOR, European symbol | Resistor | Bejoken | 454710 | 0,01
R13 | 4.3k/1% | R-EU_M0805 | M0805 | RESISTOR, European symbol | Resistor | Digikey | 311-4.30KCRTR-ND | 0,02
R14 | 1.8K/1% | R-EU_M0805 | M0805 | RESISTOR, European symbol | Resistor | Bejoken | 454658 | 0,01
R15 | 49.9/1% | R-EU_M0805 | M0805 | RESISTOR, European symbol | Resistor | Digikey | 311-49.9CRTR-ND | 0,02
R16 | 49.9/1% | R-EU_M0805 | M0805 | RESISTOR, European symbol | Resistor | Digikey | 311-49.9CRTR-ND | 0,02
R17 | 49.9/1% | R-EU_M0805 | M0805 | RESISTOR, European symbol | Resistor | Digikey | 311-49.9CRTR-ND | 0,02
R18 | 49.9/1% | R-EU_M0805 | M0805 | RESISTOR, European symbol | Resistor | Digikey | 311-49.9CRTR-ND | 0,02
R19 | 22K | R-EU_M0805 | M0805 | RESISTOR, European symbol | Resistor | Bejoken | 454684 | 0,01
U$1 | TAIMAGRPJ-003TC1 | TAIMAGRPJ-003TC1 | TAIMAGRJP-003TC1 |  |  |  |  | 40
U$2 | 11AA02E48 | 11AA02E48 | SOT23 |  | MAC Address | Digikey | 11aa02e48t-i/ttct-nd | 4
X1 | TXC-7V-SERIES 25MHz | TXC-7V-SERIES | TXC-7V-SERIES |  | XTAL 25MHz | Digikey | 887-1467-6-nd | 10,4
X2 | 32768 | CRYSTALTC26H | TC26H | CRYSTAL | Clock Chrystal | Digikey | 535-9032-nd | 2
Z1 | 1N4731(4.3V) | 1N4731(4.3V) | 1N4731 |  | Zener | Digikey | 1n4731A-tpct-nd | 3,6
 |  |  |  |  |  |  |  | 209,84

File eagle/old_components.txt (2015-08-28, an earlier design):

Count	Component	Description						Package		Supplier 1	Partnumber 1			Price 1		Supplier 2		Price 2																																																																																																																																																																																																																																																																																																																																																																																																																																																																																																																																																																																																																																																																																																																																																																																																																																																																																																																																																																																																																																																							
===========================================================================================================================================================
1		X1			XTAL 25MHz						special		Digikey  	887-1467-6-nd			1,1300																																																																																																																																																																																																																																																																																																																																																																																																																																																																																																																																																																																																																																																																																																																																																																																																																																																																																																																																																																																																																																																									
2		c1,c2		12pF Cheramic capacitor			0805		Bejoken		522417																																																																																																																																																																																																																																																																																																																																																																																																																																																																																																																																																																																																																																																																																																																																																																																																																																																																																																																																																																																																																																																										
2		c13, c14	22pF Cheramic capacitor			0805		Bejoken		522423																																																																																																																																																																																																																																																																																																																																																																																																																																																																																																																																																																																																																																																																																																																																																																																																																																																																																																																																																																																																																																																										
1					Resistor 2K/1%					0805																																																																																																																																																																																																																																																																																																																																																																																																																																																																																																																																																																																																																																																																																																																																																																																																																																																																																																																																																																																																																																																												
1					Resistor 270/1%					0805																																																																																																																																																																																																																																																																																																																																																																																																																																																																																																																																																																																																																																																																																																																																																																																																																																																																																																																																																																																																																																																												
1					XTAL 32768 Hz																																																																																																																																																																																																																																																																																																																																																																																																																																																																																																																																																																																																																																																																																																																																																																																																																																																																																																																																																																																																																																																													
2					Resistor 330					0805																																																																																																																																																																																																																																																																																																																																																																																																																																																																																																																																																																																																																																																																																																																																																																																																																																																																																																																																																																																																																																																												
1		D1			LED Gul							0805		Digikey		475-2555-1-nd			0,1600																																																																																																																																																																																																																																																																																																																																																																																																																																																																																																																																																																																																																																																																																																																																																																																																																																																																																																																																																																																																																																																									
1		D2			LED Green						0805		Digikey   	475-1410-1-nd			0,1100																																																																																																																																																																																																																																																																																																																																																																																																																																																																																																																																																																																																																																																																																																																																																																																																																																																																																																																																																																																																																																																									
1		D3			LED Red							0805		Digikey   	475-1415-1-nd			0,1100																																																																																																																																																																																																																																																																																																																																																																																																																																																																																																																																																																																																																																																																																																																																																																																																																																																																																																																																																																																																																																																									
11					Capacitor 100 nF Chermaic		0805		Bejoken		522526 					0,0276																																																																																																																																																																																																																																																																																																																																																																																																																																																																																																																																																																																																																																																																																																																																																																																																																																																																																																																																																																																																																																																									
1					Capacitor 10uF / 6.3V																																																																																																																																																																																																																																																																																																																																																																																																																																																																																																																																																																																																																																																																																																																																																																																																																																																																																																																																																																																																																																																													
1					Resistor 1M						0805																																																																																																																																																																																																																																																																																																																																																																																																																																																																																																																																																																																																																																																																																																																																																																																																																																																																																																																																																																																																																																																												
1					Capacitor 220nF					0805																																																																																																																																																																																																																																																																																																																																																																																																																																																																																																																																																																																																																																																																																																																																																																																																																																																																																																																																																																																																																																																												
1					PIC18F67J60 uP					64-TQFP 	Digikey 	PIC18F67J60-I/PT-ND		3,7800	Microchip direct 3.78/100																																																																																																																																																																																																																																																																																																																																																																																																																																																																																																																																																																																																																																																																																																																																																																																																																																																																																																																																																																																																																																																								
1					AT45DB011 EEPROM				8-SOIC 		Digikey 	AT45DB011D-SH-B-ND		0,5616																																																																																																																																																																																																																																																																																																																																																																																																																																																																																																																																																																																																																																																																																																																																																																																																																																																																																																																																																																																																																																																									
1					Resistor 100K					0805																																																																																																																																																																																																																																																																																																																																																																																																																																																																																																																																																																																																																																																																																																																																																																																																																																																																																																																																																																																																																																																												
1					ISCP pins six pin																																																																																																																																																																																																																																																																																																																																																																																																																																																																																																																																																																																																																																																																																																																																																																																																																																																																																																																																																																																																																																																													
1					Ferrite bead CHIP 220 OHM 3A 	0805		Digikey 	445-1568-1-ND			0,0490																																																																																																																																																																																																																																																																																																																																																																																																																																																																																																																																																																																																																																																																																																																																																																																																																																																																																																																																																																																																																																																									
4					Resistor 49.9 / 1%				0805																																																																																																																																																																																																																																																																																																																																																																																																																																																																																																																																																																																																																																																																																																																																																																																																																																																																																																																																																																																																																																																																																																																																																																																																																																																																																																																																																																																																																																																																																																																																																																																																																																																																																																																																																																																																																																																																																																																																																																																																																																																																																																																									
1					BD9001FSO-8 Switch regulator	8-SOIC 		Digikey   	BD9001F-E2DKR-ND		2,4900																																																																																																																																																																																																																																																																																																																																																																																																																																																																																																																																																																																																																																																																																																																																																																																																																																																																																																																																																																																																																																																									
1					Diod 1N4731(4.3V)				hole		Digikey 	1N4731A-TPCT-ND			0,0540																																																																																																																																																																																																																																																																																																																																																																																																																																																																																																																																																																																																																																																																																																																																																																																																																																																																																																																																																																																																																																																									
1					Resistor 150K					0805																																																																																																																																																																																																																																																																																																																																																																																																																																																																																																																																																																																																																																																																																																																																																																																																																																																																																																																																																																																																																																																												
1					Capacitor 4.7NF					0805																																																																																																																																																																																																																																																																																																																																																																																																																																																																																																																																																																																																																																																																																																																																																																																																																																																																																																																																																																																																																																																												
1					Capacitor 2.2uF / 50V
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

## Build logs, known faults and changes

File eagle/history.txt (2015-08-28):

Zeus
====
2014-07-07 - AKHE Rev D ready for manufacturing.
2014-06-09 - AKHE Pin 21/22 of extension connector now vin+ 
2014-06-09 - AKHE Rev D Started
2014-04-28 	AKHE Added CAN4VSCP-connector
2014-04-28	AKHE Rev C started
2012-01-25  AKHE C23/R19 markings are at opposite positions.
2012-01-19  AKHE Changed footprint for IC2 from SOP8 to SOP8W. 
2012-01-19  AKHE Rev B

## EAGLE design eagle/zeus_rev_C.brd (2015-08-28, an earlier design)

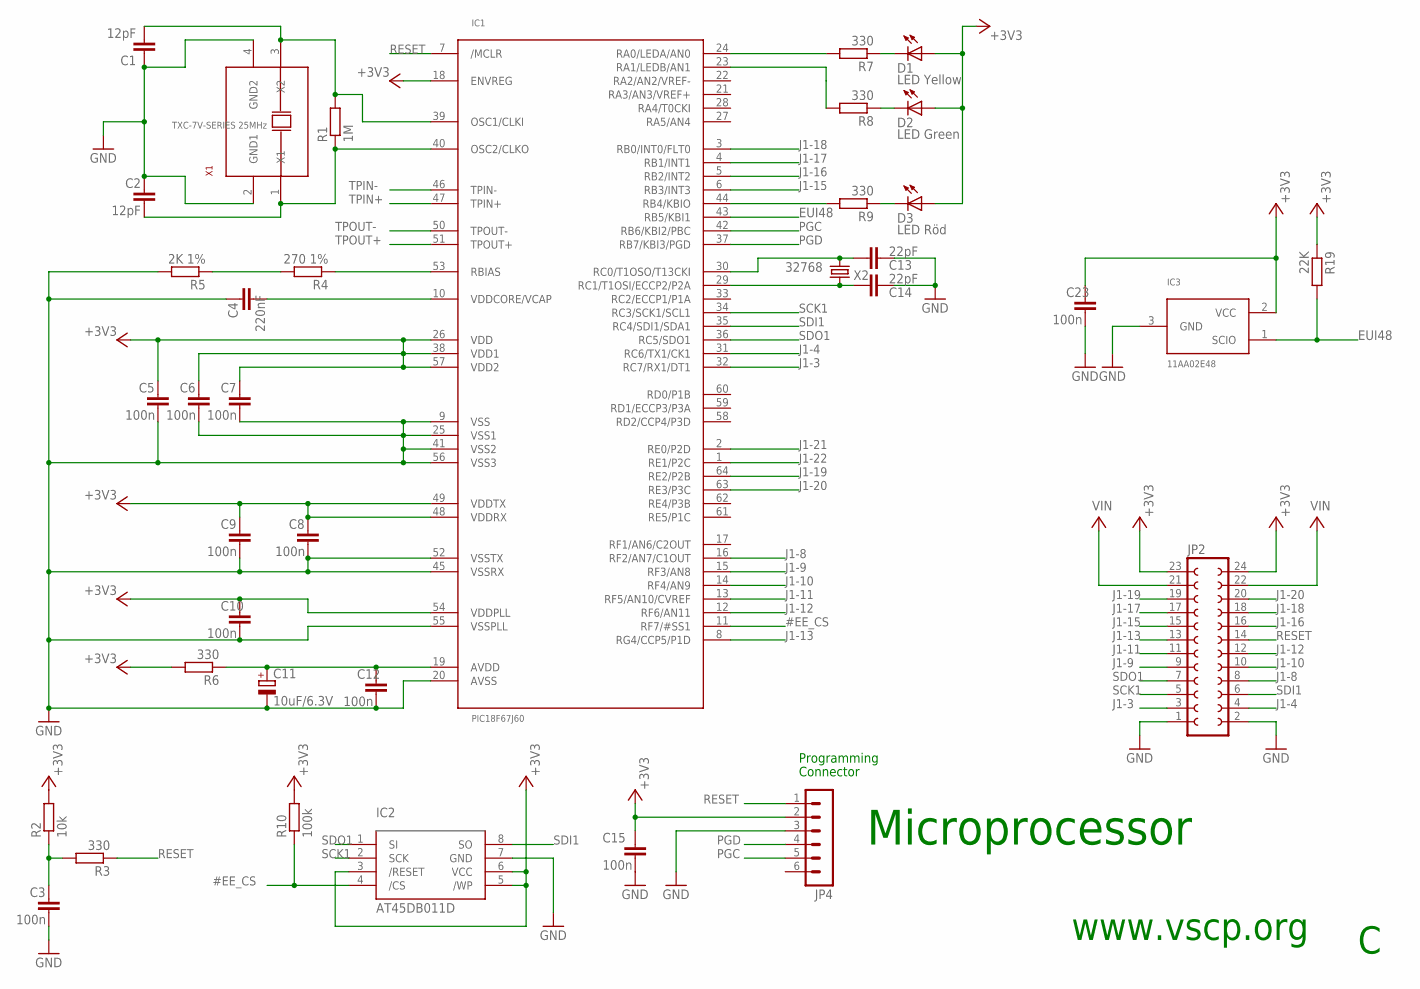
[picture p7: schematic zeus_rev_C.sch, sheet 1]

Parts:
C1, C2: 12pF; C0805
C3, C5, C6, C7, C8, C9, C10, C12, C15, C23: 100n; C0805
C4: 220nF; C0805
C11: 10uF/6.3V; SMC_P
C13, C14: 22pF; C0805
D1: LED Yellow; C2012
D2: LED Green; C2012
D3: LED Röd; C2012
IC1: PIC18F67J60; TQFP64-10X10
IC2: AT45DB011D; SOP8W
IC3: 11AA02E48; SOT23
JP2: FE12-2
JP4: MA06-1
R1: 1M; M0805
R2: 10k; M0805
R3, R6, R7, R8, R9: 330; M0805
R4: 270 1%; M0805
R5: 2K 1%; M0805
R10: 100k; M0805
R19: 22K; M0805
X1: TXC-7V-SERIES 25MHz; TXC-7V-SERIES
X2: 32768; TC26H

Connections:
#EE_CS: IC1.11 (RF7/#SS1), IC2.4 (/CS), R10.1
+3V3: C5.1, C6.1, C7.1, C8.1, C9.1, C10.1, C15.1, C23.1, D1.1 (A), D2.1 (A), D3.1 (A), IC1.18 (ENVREG), IC1.26 (VDD), IC1.38 (VDD1), IC1.48 (VDDRX), IC1.49 (VDDTX), IC1.54 (VDDPLL), IC1.57 (VDD2), IC2.3 (/RESET), IC2.5 (/WP), IC2.6 (VCC), IC3.2 (VCC), JP2.23, JP2.24, JP4.2, R2.2, R6.2, R10.2, R19.1; also elsewhere on the board
EUI48: IC1.43 (RB5/KBI1), IC3.1 (SCIO), R19.2
GND: C1.1, C2.1, C3.2, C4.1, C5.2, C6.2, C7.2, C8.2, C9.2, C10.2, C11.-, C12.2, C13.1, C14.1, C15.2, C23.2, IC1.9 (VSS), IC1.20 (AVSS), IC1.25 (VSS1), IC1.41 (VSS2), IC1.45 (VSSRX), IC1.52 (VSSTX), IC1.55 (VSSPLL), IC1.56 (VSS3), IC2.7 (GND), IC3.3 (GND), JP2.1, JP2.2, JP4.3, R5.2, X1.2 (GND1), X1.4 (GND2); also elsewhere on the board
J1-3: IC1.32 (RC7/RX1/DT1), JP2.3; also elsewhere on the board
J1-4: IC1.31 (RC6/TX1/CK1), JP2.4; also elsewhere on the board
J1-8: IC1.16 (RF2/AN7/C1OUT), JP2.8
J1-9: IC1.15 (RF3/AN8), JP2.9
J1-10: IC1.14 (RF4/AN9), JP2.10
J1-11: IC1.13 (RF5/AN10/CVREF), JP2.11
J1-12: IC1.12 (RF6/AN11), JP2.12
J1-13: IC1.8 (RG4/CCP5/P1D), JP2.13
J1-15: IC1.6 (RB3/INT3), JP2.15
J1-16: IC1.5 (RB2/INT2), JP2.16
J1-17: IC1.4 (RB1/INT1), JP2.17
J1-18: IC1.3 (RB0/INT0/FLT0), JP2.18
J1-19: IC1.64 (RE2/P2B), JP2.19
J1-20: IC1.63 (RE3/P3C), JP2.20
J1-21: IC1.2 (RE0/P2D)
J1-22: IC1.1 (RE1/P2C)
unnamed: C1.2, IC1.39 (OSC1/CLKI), R1.2, X1.3 (X2)
unnamed: C2.2, IC1.40 (OSC2/CLKO), R1.1, X1.1 (X1)
unnamed: IC1.53 (RBIAS), R4.1
unnamed: R4.2, R5.1
unnamed: C14.2, IC1.29 (RC1/T1OSI/ECCP2/P2A), X2.2
unnamed: C3.1, R2.1, R3.2
unnamed: C4.2, IC1.10 (VDDCORE/VCAP)
unnamed: C13.2, IC1.30 (RC0/T1OSO/T13CKI), X2.1
unnamed: IC1.24 (RA0/LEDA/AN0), R7.2
unnamed: IC1.23 (RA1/LEDB/AN1), R8.2
unnamed: IC1.44 (RB4/KBIO), R9.2
unnamed: D3.2 (C), R9.1
unnamed: D2.2 (C), R8.1
unnamed: D1.2 (C), R7.1
unnamed: C11.+, C12.1, IC1.19 (AVDD), R6.1
PGC: IC1.42 (RB6/KBI2/PBC), JP4.5
PGD: IC1.37 (RB7/KBI3/PGD), JP4.4
RESET: IC1.7 (/MCLR), JP2.14, JP4.1, R3.1
SCK1: IC1.34 (RC3/SCK1/SCL1), IC2.2 (SCK), JP2.5
SDI1: IC1.35 (RC4/SDI1/SDA1), IC2.8 (SO), JP2.6
SDO1: IC1.36 (RC5/SDO1), IC2.1 (SI), JP2.7
TPIN+: IC1.47 (TPIN+); also elsewhere on the board
TPIN-: IC1.46 (TPIN-); also elsewhere on the board
TPOUT+: IC1.51 (TPOUT+); also elsewhere on the board
TPOUT-: IC1.50 (TPOUT-); also elsewhere on the board
V+: JP2.21, JP2.22; also elsewhere on the board

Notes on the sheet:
Programming
Connector
Microprocessor
www.vscp.org

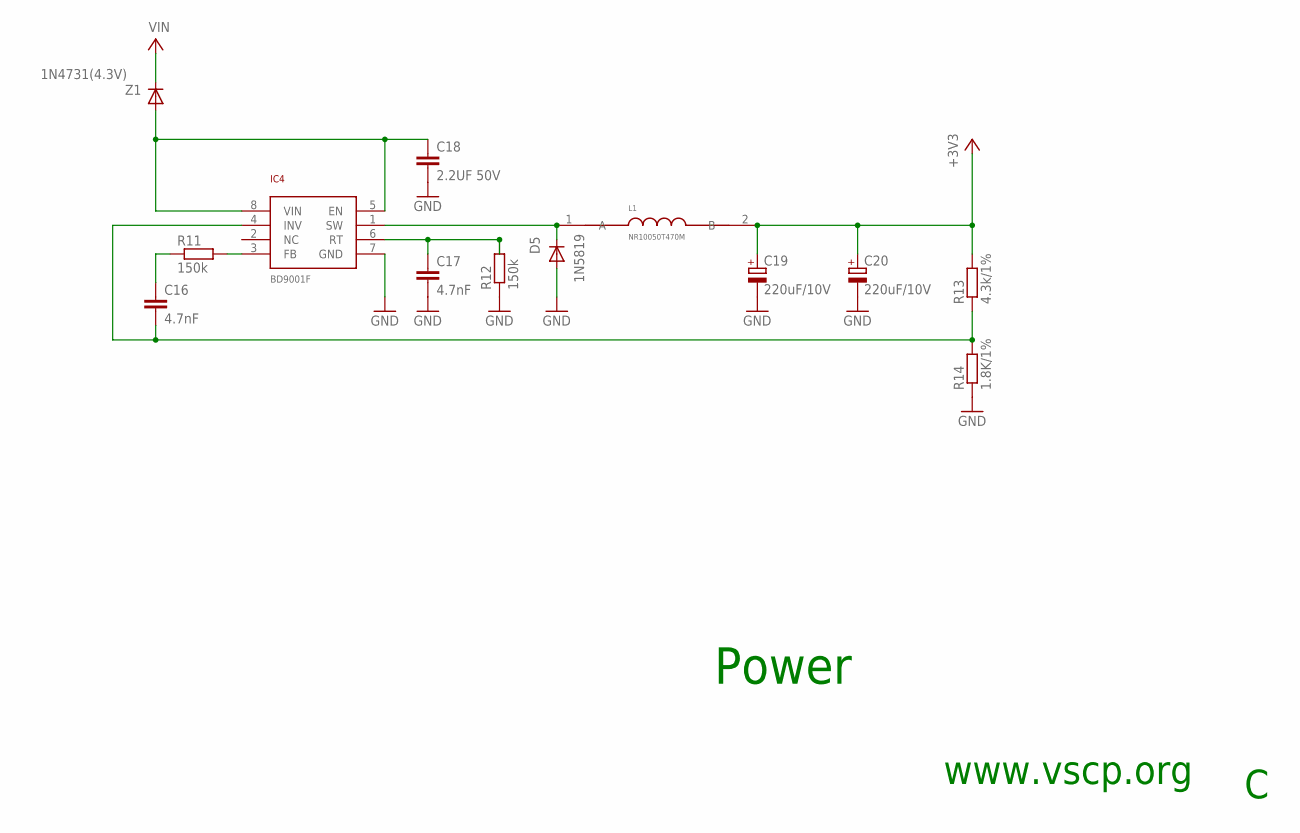
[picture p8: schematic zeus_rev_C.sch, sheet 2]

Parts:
C16, C17: 4.7nF; C0805
C18: 2.2UF 50V; C2012
C19, C20: 220uF/10V; SMC_C
D5: 1N5819; SOD-123
IC4: BD9001F; SOP8
L1: NR10050T470M
R11, R12: 150k; M0805
R13: 4.3k/1%; M0805
R14: 1.8K/1%; M0805
Z1: 1N4731(4.3V); 1N4731

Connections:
+3V3: C19.+, C20.+, L1.2 (B), R13.2; also elsewhere on the board
GND: C17.2, C18.2, C19.-, C20.-, D5.A, IC4.7 (GND), R12.1, R14.1; also elsewhere on the board
unnamed: IC4.3 (FB), R11.2
unnamed: C16.1, R11.1
unnamed: C16.2, IC4.4 (INV), R13.1, R14.2
unnamed: C17.1, IC4.6 (RT), R12.2
unnamed: C18.1, IC4.5 (EN), IC4.8 (VIN), Z1.A
unnamed: D5.C, IC4.1 (SW), L1.1 (A)
V+: Z1.C; also elsewhere on the board

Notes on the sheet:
Power
www.vscp.org

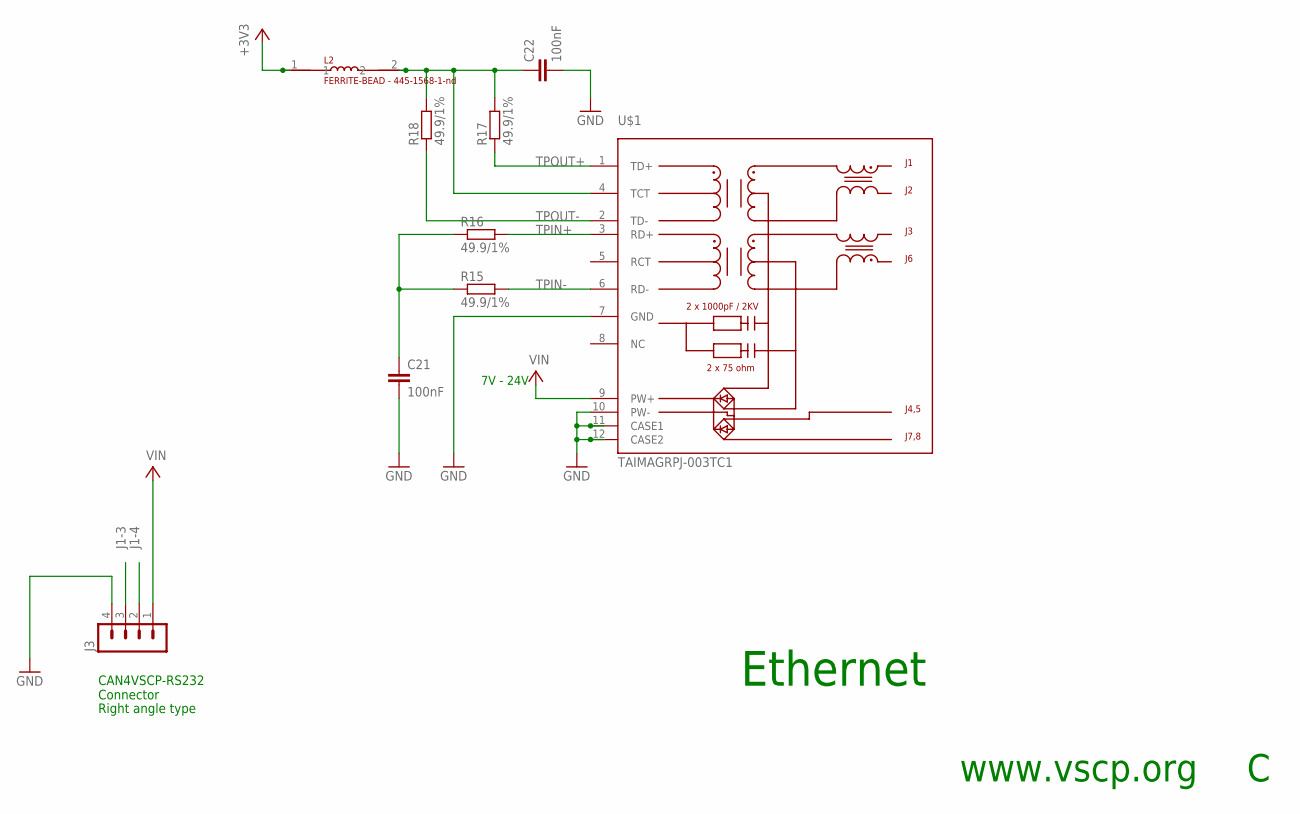
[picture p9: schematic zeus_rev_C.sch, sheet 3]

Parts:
C21, C22: 100nF; C0805
J3: MA04-1
L2: FERRITE-BEAD - 445-1568-1-nd; 0805
R15, R16, R17, R18: 49.9/1%; M0805
U$1: TAIMAGRPJ-003TC1; TAIMAGRJP-003TC1

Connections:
+3V3: L2.1; also elsewhere on the board
GND: C21.2, C22.2, J3.4, U$1.7 (GND), U$1.10 (PW-), U$1.11 (CASE1), U$1.12 (CASE2); also elsewhere on the board
J1-3: J3.3; also elsewhere on the board
J1-4: J3.2; also elsewhere on the board
unnamed: C21.1, R15.1, R16.1
unnamed: C22.1, L2.2, R17.2, R18.2, U$1.4 (TCT)
TPIN+: R16.2, U$1.3 (RD+); also elsewhere on the board
TPIN-: R15.2, U$1.6 (RD-); also elsewhere on the board
TPOUT+: R17.1, U$1.1 (TD+); also elsewhere on the board
TPOUT-: R18.1, U$1.2 (TD-); also elsewhere on the board
V+: J3.1, U$1.9 (PW+); also elsewhere on the board

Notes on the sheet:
Ethernet
7V - 24V
www.vscp.org
CAN4VSCP-RS232 Connector
Right angle type

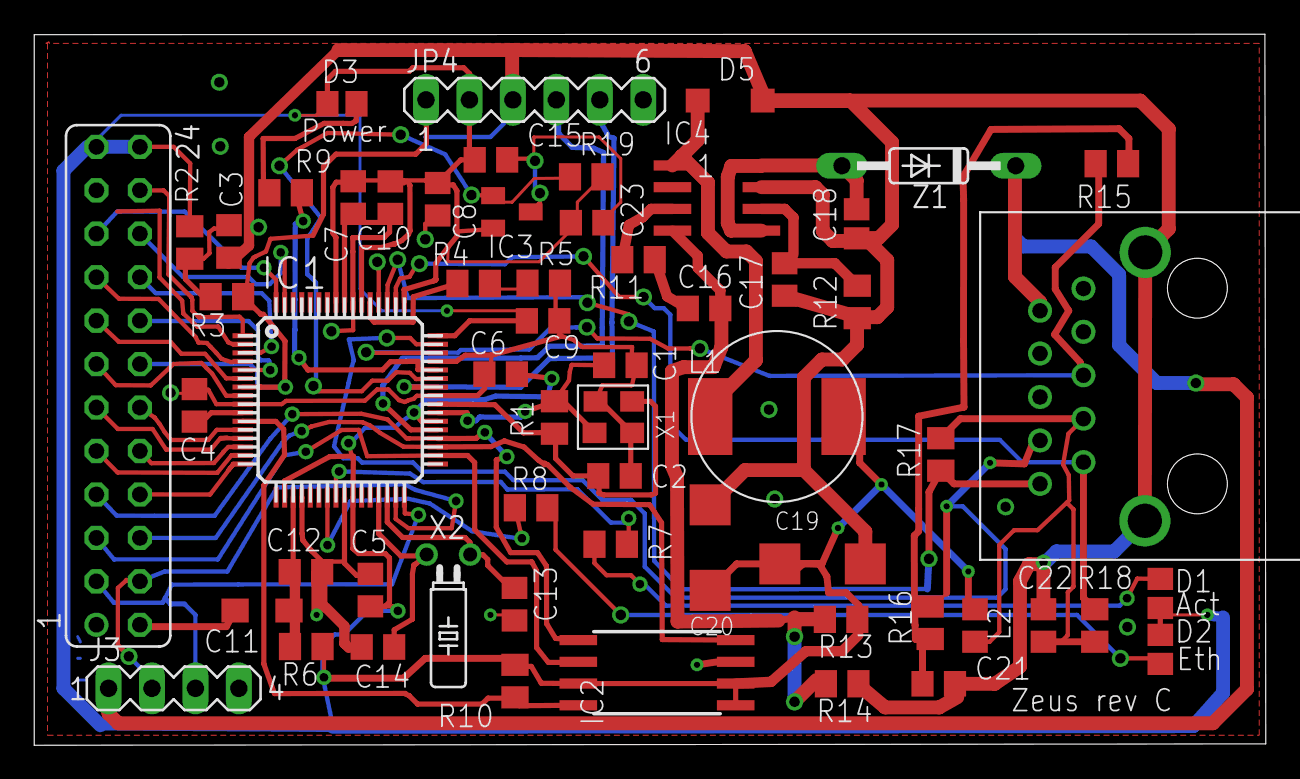
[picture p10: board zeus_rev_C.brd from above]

Board: 2 copper layers, 72.0 x 41.6 mm, 59 parts (0 on the bottom side), 52 nets.

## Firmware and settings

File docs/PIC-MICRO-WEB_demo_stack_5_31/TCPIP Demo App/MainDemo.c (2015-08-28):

/*********************************************************************
 *
 *  Main Application Entry Point and TCP/IP Stack Demo
 *  Module for Microchip TCP/IP Stack
 *   -Demonstrates how to call and use the Microchip TCP/IP stack
 *	 -Reference: Microchip TCP/IP Stack Help (TCPIP Stack Help.chm)
 *
 *********************************************************************
 * FileName:        MainDemo.c
 * Dependencies:    TCPIP.h
 * Processor:       PIC18, PIC24F, PIC24H, dsPIC30F, dsPIC33F, PIC32
 * Compiler:        Microchip C32 v1.11b or higher
 *					Microchip C30 v3.24 or higher
 *					Microchip C18 v3.36 or higher
 * Company:         Microchip Technology, Inc.
 *
 * Software License Agreement
 *
 * Copyright (C) 2002-2010 Microchip Technology Inc.  All rights
 * reserved.
 *
 * Microchip licenses to you the right to use, modify, copy, and
 * distribute:
 * (i)  the Software when embedded on a Microchip microcontroller or
 *      digital signal controller product ("Device") which is
 *      integrated into Licensee's product; or
 * (ii) ONLY the Software driver source files ENC28J60.c, ENC28J60.h,
 *		ENCX24J600.c and ENCX24J600.h ported to a non-Microchip device
 *		used in conjunction with a Microchip ethernet controller for
 *		the sole purpose of interfacing with the ethernet controller.
 *
 * You should refer to the license agreement accompanying this
 * Software for additional information regarding your rights and
 * obligations.
 *
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
 *
 * Author              Date         Comment
 *~~~~~~~~~~~~~~~~~~~~~~~~~~~~~~~~~~~~~~~~~~~~~~~~~~~~~~~~~~~~~~~~~~~~
 * Nilesh Rajbharti		4/19/01		Original (Rev. 1.0)
 * Nilesh Rajbharti		2/09/02		Cleanup
 * Nilesh Rajbharti		5/22/02		Rev 2.0 (See version.log for detail)
 * Nilesh Rajbharti		7/9/02		Rev 2.1 (See version.log for detail)
 * Nilesh Rajbharti		4/7/03		Rev 2.11.01 (See version log for detail)
 * Howard Schlunder		10/1/04		Beta Rev 0.9 (See version log for detail)
 * Howard Schlunder		10/8/04		Beta Rev 0.9.1 Announce support added
 * Howard Schlunder		11/29/04	Beta Rev 0.9.2 (See version log for detail)
 * Howard Schlunder		2/10/05		Rev 2.5.0
 * Howard Schlunder		1/5/06		Rev 3.00
 * Howard Schlunder		1/18/06		Rev 3.01 ENC28J60 fixes to TCP, 
 *									UDP and ENC28J60 files
 * Howard Schlunder		3/01/06		Rev. 3.16 including 16-bit micro support
 * Howard Schlunder		4/12/06		Rev. 3.50 added LCD for Explorer 16
 * Howard Schlunder		6/19/06		Rev. 3.60 finished dsPIC30F support, added PICDEM.net 2 support
 * Howard Schlunder		8/02/06		Rev. 3.75 added beta DNS, NBNS, and HTTP client (GenericTCPClient.c) services
 * Howard Schlunder		12/28/06	Rev. 4.00RC added SMTP, Telnet, substantially modified TCP layer
 * Howard Schlunder		04/09/07	Rev. 4.02 added TCPPerformanceTest, UDPPerformanceTest, Reboot and fixed some bugs
 * Howard Schlunder		xx/xx/07	Rev. 4.03
 * HSchlunder & EWood	08/27/07	Rev. 4.11
 * HSchlunder & EWood	10/08/07	Rev. 4.13
 * HSchlunder & EWood	11/06/07	Rev. 4.16
 * HSchlunder & EWood	11/08/07	Rev. 4.17
 * HSchlunder & EWood	11/12/07	Rev. 4.18
 * HSchlunder & EWood	02/11/08	Rev. 4.19
 * HSchlunder & EWood   04/26/08    Rev. 4.50 Moved most code to other files for clarity
 * KHesky               07/07/08    Added ZG2100-specific support
 * HSchlunder & EWood   07/24/08    Rev. 4.51
 * Howard Schlunder		11/10/08    Rev. 4.55
 * Howard Schlunder		04/14/09    Rev. 5.00
 * Howard Schlunder		07/10/09    Rev. 5.10
 * Howard Schlunder		11/18/09    Rev. 5.20
 * Howard Schlunder		04/28/10    Rev. 5.25
 * Howard Schlunder		10/19/10	Rev. 5.31
 ********************************************************************/
/*
 * This macro uniquely defines this file as the main entry point.
 * There should only be one such definition in the entire project,
 * and this file must define the AppConfig variable as described below.
 */
#define THIS_IS_STACK_APPLICATION

// configuration bits
#pragma config WDT=OFF, FOSC2=ON, FOSC=HSPLL, ETHLED=OFF, XINST=OFF

// Include all headers for any enabled TCPIP Stack functions
#include "TCPIP Stack/TCPIP.h"

#if defined(STACK_USE_ZEROCONF_LINK_LOCAL)
#include "TCPIP Stack/ZeroconfLinkLocal.h"
#endif
#if defined(STACK_USE_ZEROCONF_MDNS_SD)
#include "TCPIP Stack/ZeroconfMulticastDNS.h"
#endif

// Include functions specific to this stack application
#include "MainDemo.h"

// Used for Wi-Fi assertions
#define WF_MODULE_NUMBER   WF_MODULE_MAIN_DEMO

// Declare AppConfig structure and some other supporting stack variables
APP_CONFIG AppConfig;
static unsigned short wOriginalAppConfigChecksum;	// Checksum of the ROM defaults for AppConfig
BYTE AN0String[8];

// Use UART2 instead of UART1 for stdout (printf functions).  Explorer 16 
// serial port hardware is on PIC UART2 module.
#if defined(EXPLORER_16) || defined(PIC24FJ256DA210_DEV_BOARD)
	int __C30_UART = 2;
#endif


// Private helper functions.
// These may or may not be present in all applications.
static void InitAppConfig(void);
static void InitializeBoard(void);
static void ProcessIO(void);
#if defined(WF_CS_TRIS)
    static void WF_Connect(void);
#endif

//
// PIC18 Interrupt Service Routines
// 
// NOTE: Several PICs, including the PIC18F4620 revision A3 have a RETFIE FAST/MOVFF bug
// The interruptlow keyword is used to work around the bug when using C18
#if defined(__18CXX)
	#if defined(HI_TECH_C)
	void interrupt low_priority LowISR(void)
	#else
	#pragma interruptlow LowISR
	void LowISR(void)
	#endif
	{
	    TickUpdate();
	}
	
	#if defined(HI_TECH_C)
	void interrupt HighISR(void)
	#else
	#pragma interruptlow HighISR
	void HighISR(void)
	#endif
	{
	    #if defined(STACK_USE_UART2TCP_BRIDGE)
			UART2TCPBridgeISR();
		#endif

		#if defined(WF_CS_TRIS)
			WFEintISR();
		#endif // WF_CS_TRIS
	}

	#if !defined(HI_TECH_C)
	#pragma code lowVector=0x18
	void LowVector(void){_asm goto LowISR _endasm}
	#pragma code highVector=0x8
	void HighVector(void){_asm goto HighISR _endasm}
	#pragma code // Return to default code section
	#endif

// C30 and C32 Exception Handlers
// If your code gets here, you either tried to read or write
// a NULL pointer, or your application overflowed the stack
// by having too many local variables or parameters declared.
#elif defined(__C30__)
	void _ISR __attribute__((__no_auto_psv__)) _AddressError(void)
	{
	    Nop();
		Nop();
	}
	void _ISR __attribute__((__no_auto_psv__)) _StackError(void)
	{
	    Nop();
		Nop();
	}
	
#elif defined(__C32__)
	void _general_exception_handler(unsigned cause, unsigned status)
	{
		Nop();
		Nop();
	}
#endif


//
// Main application entry point.
//
#if defined(__18CXX)
void main(void)
#else
int main(void)
#endif
{
	static DWORD t = 0;
	static DWORD dwLastIP = 0;

	// Initialize application specific hardware
	InitializeBoard();

	#if defined(USE_LCD)
	// Initialize and display the stack version on the LCD
	LCDInit();
	DelayMs(100);
	strcpypgm2ram((char*)LCDText, "TCPStack " TCPIP_STACK_VERSION "  "
		"                ");
	LCDUpdate();
	#endif

	// Initialize stack-related hardware components that may be 
	// required by the UART configuration routines
    TickInit();
	#if defined(STACK_USE_MPFS) || defined(STACK_USE_MPFS2)
	MPFSInit();
	#endif

	// Initialize Stack and application related NV variables into AppConfig.
	InitAppConfig();

    // Initiates board setup process if button is depressed 
	// on startup
    if(BUTTON0_IO == 0u)
    {
		#if defined(EEPROM_CS_TRIS) || defined(SPIFLASH_CS_TRIS)
		// Invalidate the EEPROM contents if BUTTON0 is held down for more than 4 seconds
		DWORD StartTime = TickGet();
		LED_PUT(0x00);
				
		while(BUTTON0_IO == 0u)
		{
			if(TickGet() - StartTime > 4*TICK_SECOND)
			{
				#if defined(EEPROM_CS_TRIS)
			    XEEBeginWrite(0x0000);
			    XEEWrite(0xFF);
			    XEEWrite(0xFF);
			    XEEEndWrite();
			    #elif defined(SPIFLASH_CS_TRIS)
			    SPIFlashBeginWrite(0x0000);
			    SPIFlashWrite(0xFF);
			    SPIFlashWrite(0xFF);
			    #endif
			    
				#if defined(STACK_USE_UART)
				putrsUART("\r\n\r\nBUTTON0 held for more than 4 seconds.  Default settings restored.\r\n\r\n");
				#endif

				LED_PUT(0x0F);
				while((LONG)(TickGet() - StartTime) <= (LONG)(9*TICK_SECOND/2));
				LED_PUT(0x00);
				while(BUTTON0_IO == 0u);
				Reset();
				break;
			}
		}
		#endif

		#if defined(STACK_USE_UART)
        DoUARTConfig();
		#endif
    }

	// Initialize core stack layers (MAC, ARP, TCP, UDP) and
	// application modules (HTTP, SNMP, etc.)
    StackInit();

    #if defined(WF_CS_TRIS)
    WF_Connect();
    #endif

	// Initialize any application-specific modules or functions/
	// For this demo application, this only includes the
	// UART 2 TCP Bridge
	#if defined(STACK_USE_UART2TCP_BRIDGE)
	UART2TCPBridgeInit();
	#endif

	#if defined(STACK_USE_ZEROCONF_LINK_LOCAL)
    ZeroconfLLInitialize();
	#endif

	#if defined(STACK_USE_ZEROCONF_MDNS_SD)
	mDNSInitialize(MY_DEFAULT_HOST_NAME);
	mDNSServiceRegister(
		(const char *) "DemoWebServer",	// base name of the service
		"_http._tcp.local",			    // type of the service
		80,				                // TCP or UDP port, at which this service is available
		((const BYTE *)"path=/index.htm"),	// TXT info
		1,								    // auto rename the service when if needed
		NULL,							    // no callback function
		NULL							    // no application context
		);

    mDNSMulticastFilterRegister();			
	#endif

	// Now that all items are initialized, begin the co-operative
	// multitasking loop.  This infinite loop will continuously 
	// execute all stack-related tasks, as well as your own
	// application's functions.  Custom functions should be added
	// at the end of this loop.
    // Note that this is a "co-operative mult-tasking" mechanism
    // where every task performs its tasks (whether all in one shot
    // or part of it) and returns so that other tasks can do their
    // job.
    // If a task needs very long time to do its job, it must be broken
    // down into smaller pieces so that other tasks can have CPU time.
    while(1)
    {
        // Blink LED0 (right most one) every second.
        if(TickGet() - t >= TICK_SECOND/2ul)
        {
            t = TickGet();
            LED0_IO ^= 1;
        }

        // This task performs normal stack task including checking
        // for incoming packet, type of packet and calling
        // appropriate stack entity to process it.
        StackTask();

        // This tasks invokes each of the core stack application tasks
        StackApplications();

        #if defined(STACK_USE_ZEROCONF_LINK_LOCAL)
		ZeroconfLLProcess();
        #endif

        #if defined(STACK_USE_ZEROCONF_MDNS_SD)
        mDNSProcess();
		// Use this function to exercise service update function
		// HTTPUpdateRecord();
        #endif

		// Process application specific tasks here.
		// For this demo app, this will include the Generic TCP 
		// client and servers, and the SNMP, Ping, and SNMP Trap
		// demos.  Following that, we will process any IO from
		// the inputs on the board itself.
		// Any custom modules or processing you need to do should
		// go here.
		#if defined(STACK_USE_GENERIC_TCP_CLIENT_EXAMPLE)
		GenericTCPClient();
		#endif
		
		#if defined(STACK_USE_GENERIC_TCP_SERVER_EXAMPLE)
		GenericTCPServer();
		#endif
		
		#if defined(STACK_USE_SMTP_CLIENT)
		SMTPDemo();
		#endif
		
		#if defined(STACK_USE_ICMP_CLIENT)
		PingDemo();
		#endif
		
		#if defined(STACK_USE_SNMP_SERVER) && !defined(SNMP_TRAP_DISABLED)
		//User should use one of the following SNMP demo
		// This routine demonstrates V1 or V2 trap formats with one variable binding.
		SNMPTrapDemo();
		
		#if defined(SNMP_STACK_USE_V2_TRAP) || defined(SNMP_V1_V2_TRAP_WITH_SNMPV3)
		//This routine provides V2 format notifications with multiple (3) variable bindings
		//User should modify this routine to send v2 trap format notifications with the required varbinds.
		//SNMPV2TrapDemo();
		#endif 
		if(gSendTrapFlag)
			SNMPSendTrap();
		#endif
		
		#if defined(STACK_USE_BERKELEY_API)
		BerkeleyTCPClientDemo();
		BerkeleyTCPServerDemo();
		BerkeleyUDPClientDemo();
		#endif

		ProcessIO();

        // If the local IP address has changed (ex: due to DHCP lease change)
        // write the new IP address to the LCD display, UART, and Announce 
        // service
		if(dwLastIP != AppConfig.MyIPAddr.Val)
		{
			dwLastIP = AppConfig.MyIPAddr.Val;
			
			#if defined(STACK_USE_UART)
				putrsUART((ROM char*)"\r\nNew IP Address: ");
			#endif

			DisplayIPValue(AppConfig.MyIPAddr);

			#if defined(STACK_USE_UART)
				putrsUART((ROM char*)"\r\n");
			#endif


			#if defined(STACK_USE_ANNOUNCE)
				AnnounceIP();
			#endif

            #if defined(STACK_USE_ZEROCONF_MDNS_SD)
				mDNSFillHostRecord();
			#endif
		}
	}
}

#if defined(WF_CS_TRIS)
/*****************************************************************************
 * FUNCTION: WF_Connect
 *
 * RETURNS:  None
 *
 * PARAMS:   None
 *
 *  NOTES:   Connects to an 802.11 network.  Customize this function as needed 
 *           for your application.
 *****************************************************************************/
static void WF_Connect(void)
{
    UINT8 ConnectionProfileID;
    UINT8 channelList[] = MY_DEFAULT_CHANNEL_LIST;
    #if defined(WF_USE_POWER_SAVE_FUNCTIONS)
    BOOL  PsPollEnabled;
    #endif
    
    /* create a Connection Profile */
    WF_CPCreate(&ConnectionProfileID);

    #if defined(STACK_USE_UART)
    putrsUART("Set SSID (");
    putsUART(AppConfig.MySSID);
    putrsUART(")\r\n");
    #endif
    WF_CPSetSsid(ConnectionProfileID, 
                 AppConfig.MySSID, 
                 AppConfig.SsidLength);

    #if defined(STACK_USE_UART)
    putrsUART("Set Network Type\r\n");
	#endif
    WF_CPSetNetworkType(ConnectionProfileID, MY_DEFAULT_NETWORK_TYPE);
    
	#if defined(STACK_USE_UART)
	putrsUART("Set Scan Type\r\n");
	#endif
    WF_CASetScanType(MY_DEFAULT_SCAN_TYPE);
    
    #if defined(STACK_USE_UART)
    putrsUART("Set Channel List\r\n");
    #endif    
    WF_CASetChannelList(channelList, sizeof(channelList));
    
    #if defined(STACK_USE_UART)
    putrsUART("Set list retry count\r\n");
    #endif
    WF_CASetListRetryCount(MY_DEFAULT_LIST_RETRY_COUNT);

    #if defined(STACK_USE_UART)        
    putrsUART("Set Event Notify\r\n");    
    #endif
    WF_CASetEventNotificationAction(MY_DEFAULT_EVENT_NOTIFICATION_LIST);
    
#if defined(WF_USE_POWER_SAVE_FUNCTIONS)
    PsPollEnabled = (MY_DEFAULT_PS_POLL == WF_ENABLED);
    if (!PsPollEnabled)
    {    
        /* disable low power (PS-Poll) mode */
        #if defined(STACK_USE_UART)
        putrsUART("Disable PS-Poll\r\n");        
        #endif
        WF_PsPollDisable();
    }    
    else
    {
        /* Enable low power (PS-Poll) mode */
        #if defined(STACK_USE_UART)
        putrsUART("Enable PS-Poll\r\n");        
        #endif
        WF_PsPollEnable(TRUE);
    }    
#endif

    #if defined(STACK_USE_UART)
    putrsUART("Set Beacon Timeout\r\n");
    #endif
    WF_CASetBeaconTimeout(40);
    
    /* Set Security */
    #if (MY_DEFAULT_WIFI_SECURITY_MODE == WF_SECURITY_OPEN)
        #if defined(STACK_USE_UART)
        putrsUART("Set Security (Open)\r\n");
        #endif
    #elif (MY_DEFAULT_WIFI_SECURITY_MODE == WF_SECURITY_WEP_40)
        #if defined(STACK_USE_UART)
        putrsUART("Set Security (WEP40)\r\n");
        #endif
    #elif (MY_DEFAULT_WIFI_SECURITY_MODE == WF_SECURITY_WEP_104)
        #if defined(STACK_USE_UART)
        putrsUART("Set Security (WEP104)\r\n");
        #endif
    #elif MY_DEFAULT_WIFI_SECURITY_MODE == WF_SECURITY_WPA_WITH_KEY 
        #if defined(STACK_USE_UART)
        putrsUART("Set Security (WPA with key)\r\n");
        #endif
    #elif MY_DEFAULT_WIFI_SECURITY_MODE == WF_SECURITY_WPA2_WITH_KEY 
        #if defined(STACK_USE_UART)
        putrsUART("Set Security (WPA2 with key)\r\n");
        #endif
    #elif MY_DEFAULT_WIFI_SECURITY_MODE == WF_SECURITY_WPA_WITH_PASS_PHRASE
        #if defined(STACK_USE_UART)
        putrsUART("Set Security (WPA with pass phrase)\r\n");
        #endif
    #elif MY_DEFAULT_WIFI_SECURITY_MODE == WF_SECURITY_WPA2_WITH_PASS_PHRASE
        #if defined(STACK_USE_UART)
        putrsUART("Set Security (WPA2 with pass phrase)\r\n");    
        #endif
    #elif MY_DEFAULT_WIFI_SECURITY_MODE == WF_SECURITY_WPA_AUTO_WITH_KEY
        #if defined(STACK_USE_UART)
        putrsUART("Set Security (WPA with key, auto-select)\r\n");
        #endif
    #elif MY_DEFAULT_WIFI_SECURITY_MODE == WF_SECURITY_WPA_AUTO_WITH_PASS_PHRASE
        #if defined(STACK_USE_UART)
        putrsUART("Set Security (WPA with pass phrase, auto-select)\r\n");
        #endif
    #endif /* MY_DEFAULT_WIFI_SECURITY_MODE */

    WF_CPSetSecurity(ConnectionProfileID,
                     AppConfig.SecurityMode,
                     AppConfig.WepKeyIndex,   /* only used if WEP enabled */
                     AppConfig.SecurityKey,
                     AppConfig.SecurityKeyLength);
    #if defined(STACK_USE_UART)                     
    putrsUART("Start WiFi Connect\r\n");        
    #endif
    WF_CMConnect(ConnectionProfileID);
}   
#endif /* WF_CS_TRIS */

// Writes an IP address to the LCD display and the UART as available
void DisplayIPValue(IP_ADDR IPVal)
{
//	printf("%u.%u.%u.%u", IPVal.v[0], IPVal.v[1], IPVal.v[2], IPVal.v[3]);
    BYTE IPDigit[4];
	BYTE i;
#ifdef USE_LCD
	BYTE j;
	BYTE LCDPos=16;
#endif

	for(i = 0; i < sizeof(IP_ADDR); i++)
	{
	    uitoa((WORD)IPVal.v[i], IPDigit);

		#if defined(STACK_USE_UART)
			putsUART((char *) IPDigit);
		#endif

		#ifdef USE_LCD
			for(j = 0; j < strlen((char*)IPDigit); j++)
			{
				LCDText[LCDPos++] = IPDigit[j];
			}
			if(i == sizeof(IP_ADDR)-1)
				break;
			LCDText[LCDPos++] = '.';
		#else
			if(i == sizeof(IP_ADDR)-1)
				break;
		#endif

		#if defined(STACK_USE_UART)
			while(BusyUART());
			WriteUART('.');
		#endif
	}

	#ifdef USE_LCD
		if(LCDPos < 32u)
			LCDText[LCDPos] = 0;
		LCDUpdate();
	#endif
}

// Processes A/D data from the potentiometer
static void ProcessIO(void)
{
#if defined(__C30__) || defined(__C32__)
    // Convert potentiometer result into ASCII string
    uitoa((WORD)ADC1BUF0, AN0String);
#else
    // AN0 should already be set up as an analog input
    ADCON0bits.GO = 1;

    // Wait until A/D conversion is done
    while(ADCON0bits.GO);

	// AD converter errata work around (ex: PIC18F87J10 A2)
	#if !defined(__18F87J50) && !defined(_18F87J50) && !defined(__18F87J11) && !defined(_18F87J11) 
	{
		BYTE temp = ADCON2;
		ADCON2 |= 0x7;	// Select Frc mode by setting ADCS0/ADCS1/ADCS2
		ADCON2 = temp;
	}
	#endif

    // Convert 10-bit value into ASCII string
    uitoa(*((WORD*)(&ADRESL)), AN0String);
#endif
}


/****************************************************************************
  Function:
    static void InitializeBoard(void)

  Description:
    This routine initializes the hardware.  It is a generic initialization
    routine for many of the Microchip development boards, using definitions
    in HardwareProfile.h to determine specific initialization.

  Precondition:
    None

  Parameters:
    None - None

  Returns:
    None

  Remarks:
    None
  ***************************************************************************/
static void InitializeBoard(void)
{	
	// LEDs
	LED0_TRIS = 0;
	LED1_TRIS = 0;
	LED2_TRIS = 0;
	LED3_TRIS = 0;
	LED4_TRIS = 0;
	LED5_TRIS = 0;
	LED6_TRIS = 0;
	LED7_TRIS = 0;
	LED_PUT(0x00);
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

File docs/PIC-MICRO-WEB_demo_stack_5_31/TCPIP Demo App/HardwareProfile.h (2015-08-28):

/*********************************************************************
 *
 *	Hardware specific definitions
 *
 *********************************************************************
 * FileName:        HardwareProfile.h
 * Dependencies:    None
 * Processor:       PIC18, PIC24F, PIC24H, dsPIC30F, dsPIC33F, PIC32
 * Compiler:        Microchip C32 v1.10 or higher
 *					Microchip C30 v3.12 or higher
 *					Microchip C18 v3.34 or higher
 *					HI-TECH PICC-18 PRO 9.63PL2 or higher
 * Company:         Microchip Technology, Inc.
 *
 * Software License Agreement
 *
 * Copyright (C) 2002-2010 Microchip Technology Inc.  All rights
 * reserved.
 *
 * Microchip licenses to you the right to use, modify, copy, and
 * distribute:
 * (i)  the Software when embedded on a Microchip microcontroller or
 *      digital signal controller product ("Device") which is
 *      integrated into Licensee's product; or
 * (ii) ONLY the Software driver source files ENC28J60.c, ENC28J60.h,
 *		ENCX24J600.c and ENCX24J600.h ported to a non-Microchip device
 *		used in conjunction with a Microchip ethernet controller for
 *		the sole purpose of interfacing with the ethernet controller.
 *
 * You should refer to the license agreement accompanying this
 * Software for additional information regarding your rights and
 * obligations.
 *
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
 *
 * Author               Date		Comment
 *~~~~~~~~~~~~~~~~~~~~~~~~~~~~~~~~~~~~~~~~~~~~~~~~~~~~~~~~~~~~~~~~~~~~
 * Howard Schlunder		09/01/2010	Converted to a stub
 ********************************************************************/

// These definitions are set in the MPLAB Project settings.  If you are starting
// a new project, you should start by modifying one of the pre-existing .mcp 
// files.  To modify the macro used, in MPLAB IDE, click on Project -> Build 
// Options... -> Project -> MPLAB XXX C Compiler -> Preprocessor Macros -> 
// Add.... Note that you may also have to add this macro to the assembler 
// (MPLAB XXX Assembler tab).

//#define	OLIMEX_MAXI		// based on PIC18F97J60
//#define	OLIMEX_WEB		
#define	OLIMEX_MICRO		
//#define	OLIMEX_MINI		// based on PIC18F25J10
//#define	OLIMEX_P67J60		// based on PIC18F67J60

#if defined(OLIMEX_MAXI) || defined(OLIMEX_WEB) || defined(OLIMEX_MINI) || \
		defined(OLIMEX_MICRO) || defined(OLIMEX_P67J60)
	#define OLIMEX_HW
#endif 

#if defined(YOUR_BOARD)
	#include "Alternative Configurations/HardwareProfile YOUR_BOARD.h"
*#elif defined(INTERNET_RADIO)
	// DM183033 Internet Radio board, PIC18F67J60, internal Ethernet
	#include "Alternative Configurations/HardwareProfile INTERNET_RADIO.h"
#elif defined(PICDEMNET2_INTERNAL_ETHERNET)
	// DM163024 PICDEM.net 2 board, PIC18F97J60, internal Ethernet (J1 Ethernet jack)
	#include "Alternative Configurations/HardwareProfile PICDEMNET2_INTERNAL_ETHERNET.h"
#elif defined(PICDEMNET2_ONBOARD_ENC28J60)
	// DM163024 PICDEM.net 2 board, PIC18F97J60, onboard ENC28J60 (J2 Ethernet jack)
	#include "Alternative Configurations/HardwareProfile PICDEMNET2_ONBOARD_ENC28J60.h"
#elif defined(PICDEMNET2_ENC624J600)
	// DM163024 PICDEM.net 2 board, PIC18F97J60, AC164132 Fast 100Mbps Ethernet PICtail/PICtail Plus (ENC624J600)
	#include "Alternative Configurations/HardwareProfile PICDEMNET2_ENC624J600.h"
#elif defined(PICDEMNET2_MRF24WB0M)
	// DM163024 PICDEM.net 2 board, PIC18F97J60, AC164136-4 MRF24WB0MA Wi-Fi PICtail/PICtail Plus
	#include "Alternative Configurations/HardwareProfile PICDEMNET2_MRF24WB0M.h"
#elif defined(PIC18_EXPLORER_ENC28J60)
	// DM183032 PIC18 Explorer board, PIC18F8722/PIC18F87J50/PIC18F87J10/PIC18F87J11/possibly others, AC164121 Ethernet PICtail (ENC28J60)
	#include "Alternative Configurations/HardwareProfile PIC18_EXPLORER_ENC28J60.h"
#elif defined(PIC18_EXPLORER_ENC624J600)
	// DM183032 PIC18 Explorer board, PIC18F8722/PIC18F87J50/PIC18F87J10/PIC18F87J11/possibly others, AC164132 Fast 100Mbps Ethernet PICtail/PICtail Plus (ENC624J600)
	#include "Alternative Configurations/HardwareProfile PIC18_EXPLORER_ENC624J600.h"
#elif defined(PIC18_EXPLORER_MRF24WB0M)
	// DM183032 PIC18 Explorer board, PIC18F8722/PIC18F87J50/PIC18F87J10/PIC18F87J11/possibly others, AC164136-4 MRF24WB0MA Wi-Fi PICtail/PICtail Plus
	#include "Alternative Configurations/HardwareProfile PIC18_EXPLORER_MRF24WB0M.h"
#elif defined(PIC24FJ256DA210_DEV_BOARD_ENC28J60)
	// DM240312 PIC24FJ256DA210 Development Board, PIC24FJ256DA210, AC164123 Ethernet PICtail Plus (ENC28J60)
	#include "Alternative Configurations/HardwareProfile PIC24FJ256DA210_DEV_BOARD_ENC28J60.h"
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
